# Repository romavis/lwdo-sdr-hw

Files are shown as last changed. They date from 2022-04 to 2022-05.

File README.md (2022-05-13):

# What

**LWDO-SDR** is an experimental device for wide-band LF/VLF radio reception and using LF/VLF signals for precise timekeeping and generic DSP/SDR research purposes.

The name LWDO-SDR *(**l**ong-**w**ave **d**isciplined **o**scillator with **s**oftware **d**efined **r**adio)* is a moniker aking to a widely-used *GPSDO* term, but instead of GPS we use signals transmitted within long wave radio band, and SDR for signal processing.

# Goals

LWDO-SDR is built upon following ideas:
- Wide dynamic range capture of the whole LF/VLF radio spectrum (up to 500 KHz)
  - Simultaneous reception of any number of stations
  - Exposing it as a WebSDR (for the fun of it?)
- Precise built-in VCTCXO oscillator
  - Generates tightly controlled ADC sample clock that allows for SDR processing using large-time-constant averaging
  - Digitally-controlled (via 16 bit DAC), and can be disciplined by:
    - External 1 PPS or 1,2,5,10MHz reference (via DPLL)
    - Received radio signals
- Synchronous capture from multiple antennas (up to 4)
  - Experiments with urban noise suppression SDR algorithms 
  - Directional reception (using e.g. two or three loop antennas)
- Raw data streaming over USB High Speed interface, processing on the USB host device (PC, RaspberryPi, etc.)
  - Because we don't want to be limited by computing power of an embedded MCU or DSP
- Single PCB, two form-factors:
  - Standalone, USB bus-powered - for ease of use and portability (uses Hammond 1455P1601 case)
  - Embedded, self-powered - for use within e.g. a standalone clock source unit within the home lab.

Some signals that can be received by LWDO-SDR are:
- [DCF77 - 77.5KHz](https://en.wikipedia.org/wiki/DCF77)
- [MSF - 60 KHz](https://en.wikipedia.org/wiki/Time_from_NPL_(MSF))
- [RBU - 66.67 KHz](https://en.wikipedia.org/wiki/RBU_(radio_station))
- [TDF - 162 KHz](https://en.wikipedia.org/wiki/ALS162_time_signal)
- [Loran - 100 KHz](https://en.wikipedia.org/wiki/Loran-C)

# Drawings

PDF renders:
- [Schematic](./doc/schematic-rev1.0.pdf)
- [PCB visualisation](./doc/pcb-rev1.0.pdf)

Curious ones are kindly asked to look into the original KiCad 6.0.4 CAD files, which include full PCB drawings and BOM information.

Photo of assembled board can be seen [here](./doc/pcb-photo-rev1.0.jpg).

# HW description

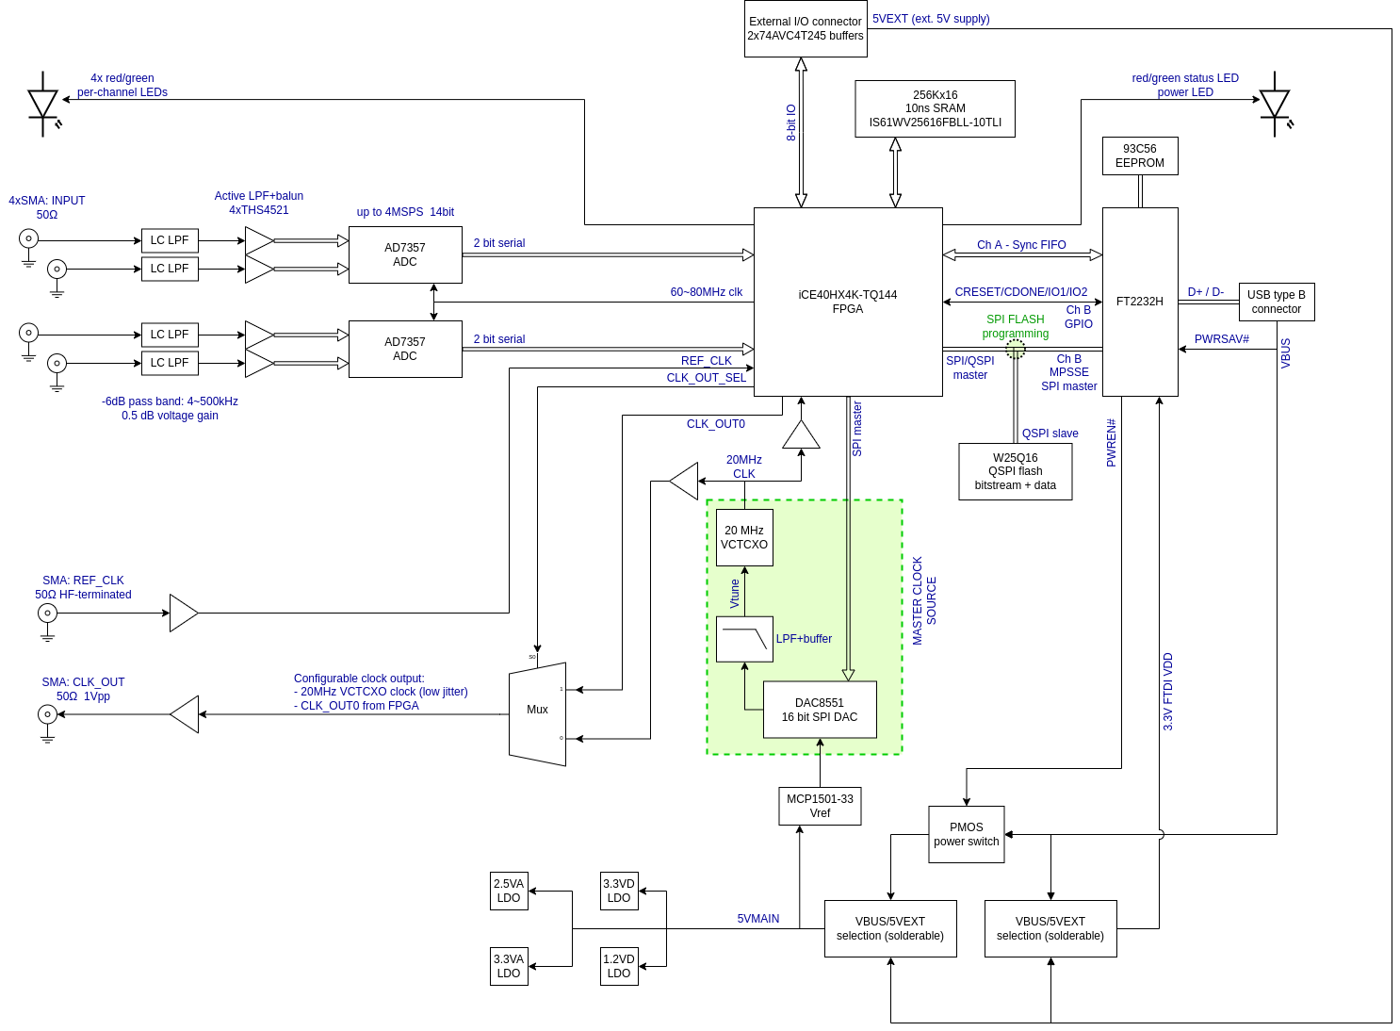
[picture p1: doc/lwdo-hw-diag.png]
Block diagram


### FPGA

The core of the LWDO-SDR is a low-end FPGA - *ICE40HX4K-TQ144* - that has:
- 3520x 4-input LUT, 1 FF logic cells (7680x with Yosys toolchain)
- 20x 4kbit dual-port block RAM cells (32x with Yosys)
- 2x PLLs
- DDR IO cells
- No hardware multipliers
- Typically achievable clock rates of 40~100MHz (depending on the design)

This FPGA has been chosen for its price and hobbyist-friendliness: TQFP144 can be soldered by hand and allows using 2-layer PCB. However, it is rather small so e.g. it may not be possible to use any kind of softCPU there (remains to be seen..). Any kind of sophisticated DSP is also out of the question, since there are no hardware multipliers.

The bitstream together with any extra user data is stored within 2 MByte QSPI flash - *W25Q16JV*.

FPGA is also connected to a 10 ns 512 KByte SRAM with 16 bit data bus - *IS61WV25616FBLL-10TLI*. At this moment it is not clear how much useful the SRAM may be, given overall FPGA footprint constraints.

### USB

USB 2.0 High Speed is implemented by FTDI FT2232H chip. It has two external channels, allocated as follows:
- Channel A - synchronous FIFO - allows data streaming from/to FPGA up to 40 MByte/s over USB bulk endpoints
- Channel B - MPSSE (SPI) + GPIO - to program bitstream SPI flash and handle CRESET, CDONE, and a pair of extra GPIO-like signals from FPGA (similar to how it's done on the [iCEstick](https://www.latticesemi.com/icestick). Available only when channel A is not in use.

### RF front-end

The board features four input channels for RF signals. All channels are the same:
1. 50 ohm DC-terminated SMA connector.
2. SD12C TVS ESD / overvoltage suppressor.
3. 2nd (3rd) order LC LPF (-3dB cutoff circa 530 KHz, rolloff 12 dB/oct).
4. Schottky diode overvoltage protection.
5. THS4521 fully-differential amplifier, performing unbalanced-balanced conversion and connected as a 2nd order LPF (-3dB cutoff circa 460 KHz, rolloff 12 dB/oct).
6. Passive RC LPF providing tank capacitance for driving the ADC (-3dB cutoff circa 1 MHz, rolloff 6 dB/oct)

### ADC

Board uses two [AD7357](https://www.analog.com/media/en/technical-documentation/data-sheets/AD7357.pdf), which is a 2-ch simulatenous-sampling 4.2 MSPS 14 bit SAR ADC. The output from each ADC is 2-bit serial bus. At a max sampling rate of 4.2 MSPS this ADC requires serial clock circa 80 MHz, which is provided by the FPGA.

**Note** to achieve timing closure for FPGA-ADC interface, taking into account propagation delays, setup times of ICE40HX IO cells, and especially AD7357 data valid delay (up to 9 ns), the generated clock is resampled on the FPGA pin:
- ICE40 outputs clock on the SCLK line (pin 15 or 20).
- ICE40 samples SCLK line via the input buffer of pin 20, and feeds that clock to the global clock net.
Compared to simply driving internal clock to the pin, this allows to take "global clock net -> pin output" delay (circa 2.5 ns) out of the timing equation.

### Clock source

[DOT050V-020.0M](http://www.conwin.com/datasheets/tx/tx395.pdf) VCTCXO from Connor-Winfield provides master 20 MHz clock for the FPGA, from which all the other clocks are generated using on-die PLLs.
DOT050V is a highly stable precision oscillator. Notable specs are:
- Factory frequency calibration: ±1 ppm
- Stability vs temperature 0~70 °C: ±50 **ppb**
- Stability vs load, supply voltage: ±20 ppb
- Aging over first year: ±300 ppb
- Voltage control frequency pulling range: at least ±10 ppm
- Comes in a standard 9x14mm SMT package

If needed, DOT050V can be easily replaced by some other, potentially cheaper, 3.3V VCTCXO or VCXO directly or through a simple adapter PCB (or DIY-style: some Kynar wire and hot glue). LWDO-SDR contains buffering circuitry that can accept oscillators with both square wave and (clipped) sine wave output.

The oscillator is voltage-controlled through by means of:
- 16-bit SPI DAC [DAC8551](https://www.ti.com/lit/ds/symlink/dac8551.pdf) driven by SPI master implemented on FPGA.
- DAC Vref provided by [MCP1501](https://ww1.microchip.com/downloads/en/DeviceDoc/20005474E.pdf), powered from filtered, unregulated 5V rail. 
- 1st order passive RC LPF (-3dB cutoff circa 160 Hz).
- Non-inverting buffer using [NCS325](www.onsemi.com/pub/Collateral/NCS325-D.PDF) rail-to-rail low-drift low-offset precision OpAmp.

### External clock input and output

There are two extra SMA connectors: one is for external clock input, one is for clock output from the board.

Clock output provides 1 Vpkpk 50 ohm terminated square wave output, AC or DC coupled (controlled by jumper). Output clock may come from one of two sources:
1. Dedicated FPGA pin.
2. 20 MHz master clock from VCTCXO.
The source is selected via a hardware LVCMOS multiplexer chip, controlled by the FPGA.

External clock input is 50 ohm terminated (above ~3MHz), AC or DC coupled. It is buffered and squared by a chain of unbuffered and buffered LVCMOS inverters, and fed to a dedicated FPGA pin.

**NOTE** clock input circuitry depicted on the schematic is sub-optimal. See "Errata" section below.

### External I/O

To allow LWDO-SDR PCB to be embedded, there's a 20-pin IDC ribbon cable connector which provides:
- 8 bit I/O bus connected to the FPGA:
  - Buffered via unidirectional 74AVC4T245 level translators.
  - Direction control for I/O lines is manual, by soldering/desoldering bridge resistors onto PCB.
  - Wired to a ribbon cable in G-S-G order, impedance-matched to a standard 1.27mm-pitch cable.
- External VDDIO supply for the level translators.
- External 5V supply for powering up the board (instead of using USB VBUS).

### LEDs

Board has 6 red/green bi-LEDs [WP130WCP/2EGW](https://www.kingbrightusa.com/images/catalog/SPEC/WP130WCP-2EGW.pdf):
- 4 for monitoring input status (located next to the input connectors)
- 1 for monitoring system status (located next to the USB)
- 1 hard-wired as a green power LED (located next to the USB)

### PCB

The board itself is 2-layer, designed to be manufacturable by [Eurocircuits](https://www.eurocircuits.com/) PCB Proto service according to Class 5C (0.175mm track, 0.25mm annular ring, 0.25mm smallest final hole).

# Software

The testing of rev 1.0 board is, as of 10 May 2022, currently ongoing. The software development is WIP. Source code of FPGA and host SW will be published on GitHub as soon as I have something ready.

# Errata

### Issue 1 - CLK_IN buffer instability

**Symptom:** when AC-coupled, in absence of input signal, or when input signal is weak or slowly-changing (low frequency sine wave), the output of clock buffer contains a lot of random 0->1, 1->0 transitions.

**Cause:** input buffer, implemented with 2x LVCMOS unbuffered invertors, has very high analog gain (circa 40~50dB). That amplifies all kinds of noise when the input signal is not strong enough. Buffered LVCMOS invertors ampify and square that noise signal even further.

**Solution:** problem can be solved by adding hysteresis (Schmitt-trigger action) to the input buffer. For that, an extra 100K resistor needs to be soldered on top of the PCB per schematic shown below:

[Errata-1-rework-schematic](./doc/errata-issue1-rework.png)

# License

Copyright 2022 Roman Dobrodii

SPDX-License-Identifier: Apache-2.0 WITH SHL-2.1

Licensed under the Solderpad Hardware License v 2.1 (the “License”); you may not
use this work except in compliance with the License, or, at your option, the
Apache License version 2.0. You may obtain a copy of the License at

https://solderpad.org/licenses/SHL-2.1/

Unless required by applicable law or agreed to in writing, any work distributed
under the License is distributed on an “AS IS” BASIS, WITHOUT WARRANTIES OR
CONDITIONS OF ANY KIND, either express or implied. See the License for the
specific language governing permissions and limitations under the License.

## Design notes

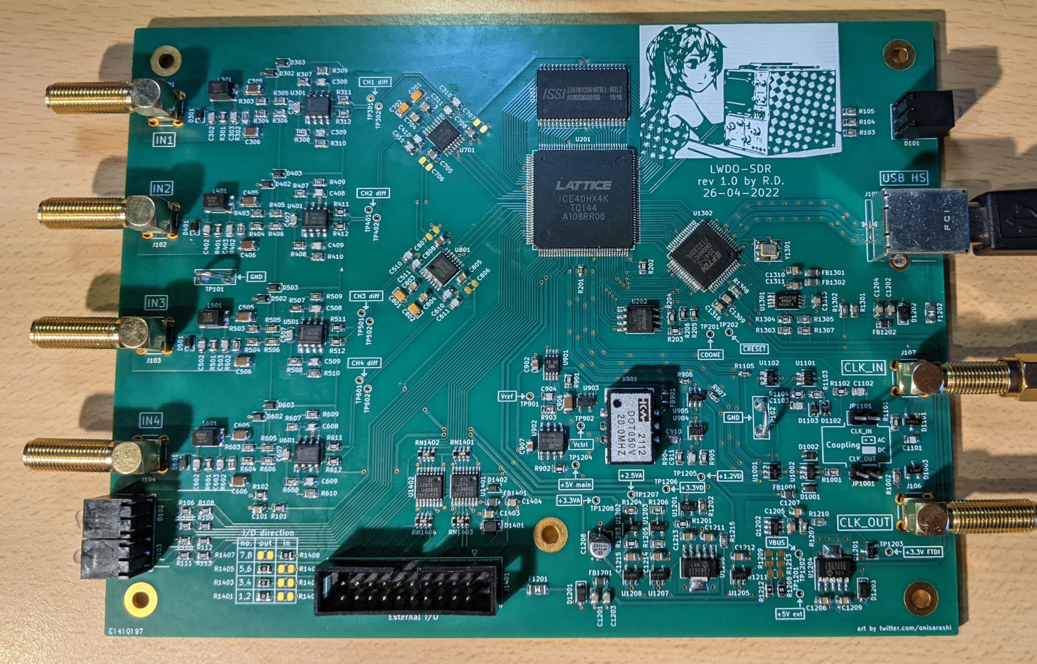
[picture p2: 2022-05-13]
doc/pcb-photo-rev1.0.jpg

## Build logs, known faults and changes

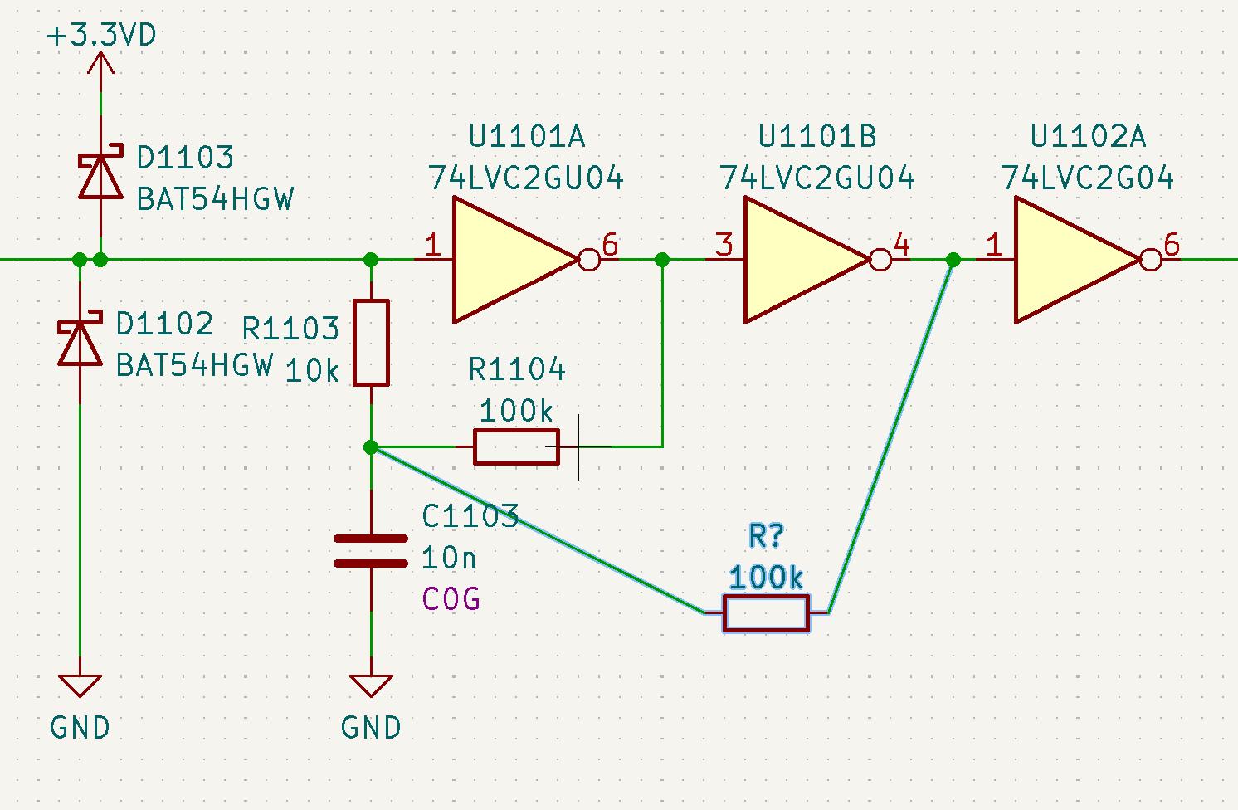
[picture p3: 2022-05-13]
doc/errata-issue1-rework.png

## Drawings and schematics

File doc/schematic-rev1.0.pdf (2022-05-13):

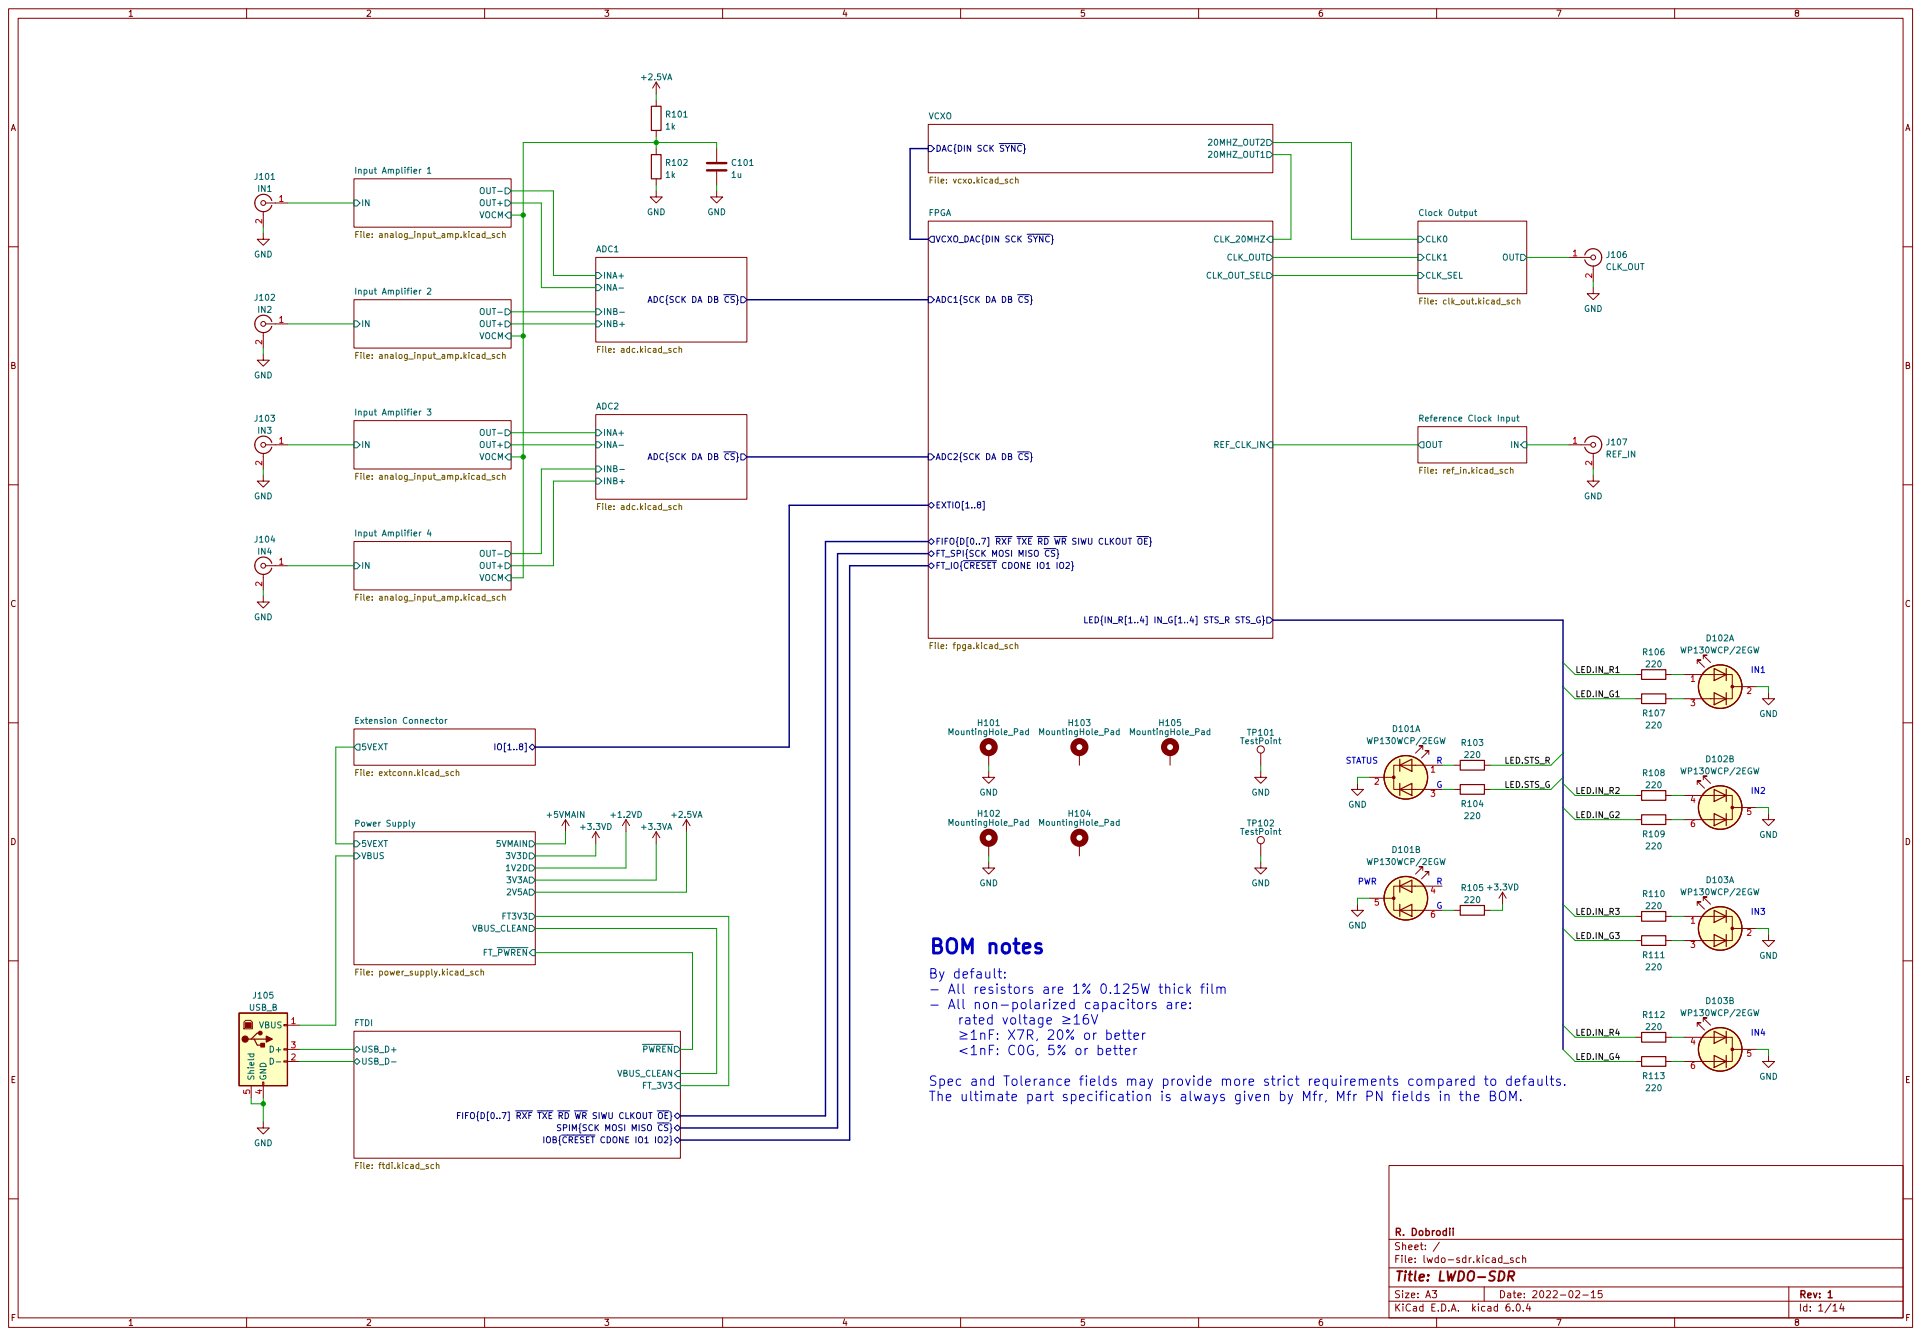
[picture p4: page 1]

20MHZ_OUT2 DAC{DIN SCK ~{SYNC}} VCXO

ADC{SCK DA DB ~{CS}}

ADC1{SCK DA DB ~{CS}}

Reference Clock Input File: ref_in.kicad_sch

ADC2{SCK DA DB ~{CS}}

FIFO{D[0..7] ~{RXF} ~{TXE} ~{RD} ~{WR} SIWU CLKOUT ~{OE}}

- All resistors are 1% 0.125W thick film
- All non-polarized capacitors are:
<1nF: C0G, 5% or better

IOB{~{CRESET} CDONE IO1 IO2} USB_D- USB_D+ FTDI File: ftdi.kicad_sch

FIFO{D[0..7] ~{RXF} ~{TXE} ~{RD} ~{WR} SIWU CLKOUT ~{OE}} VBUS_CLEAN

Spec and Tolerance fields may provide more strict requirements compared to defaults.

SPIM{SCK MOSI MISO ~{CS}}

File: lwdo-sdr.kicad_sch Sheet: / R. Dobrodii

Id: 1/14 Title: LWDO-SDR

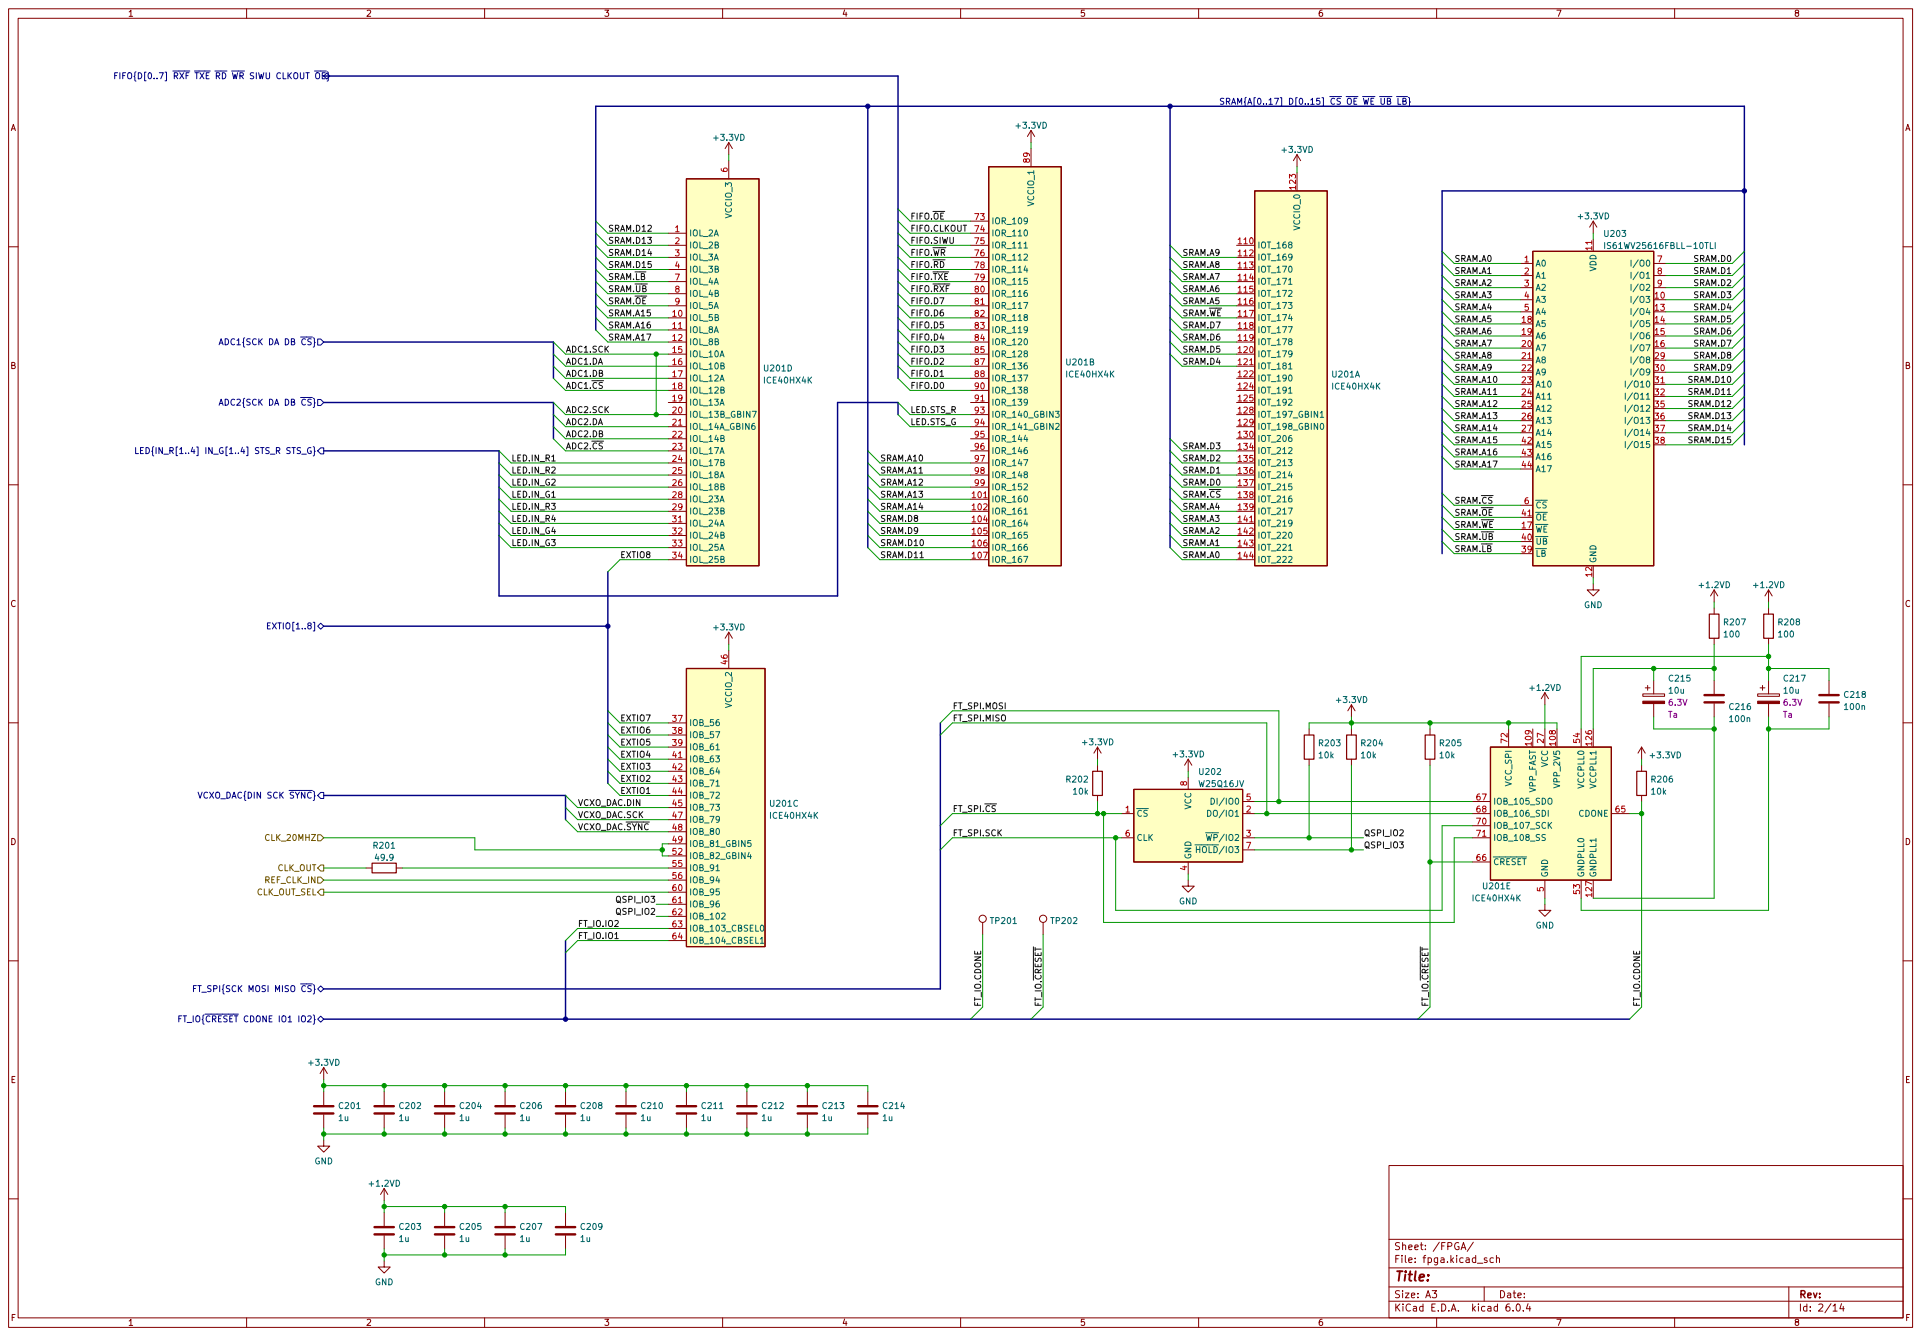
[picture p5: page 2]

FIFO{D[0..7] ~{RXF} ~{TXE} ~{RD} ~{WR} SIWU CLKOUT ~{OE}}

ADC1{SCK DA DB ~{CS}}

SRAM.A13 SRAM.A11 FIFO.D0 SRAM.A12

SRAM.~{UB} SRAM.A13 SRAM.A12

VCXO_DAC{DIN SCK ~{SYNC}} CLK_OUT EXTIO[1..8]

4 DI/IO0 5 CLK 6 ~{HOLD}/IO3 7 VCC

FT_SPI{SCK MOSI MISO ~{CS}}

File: fpga.kicad_sch Sheet: /FPGA/

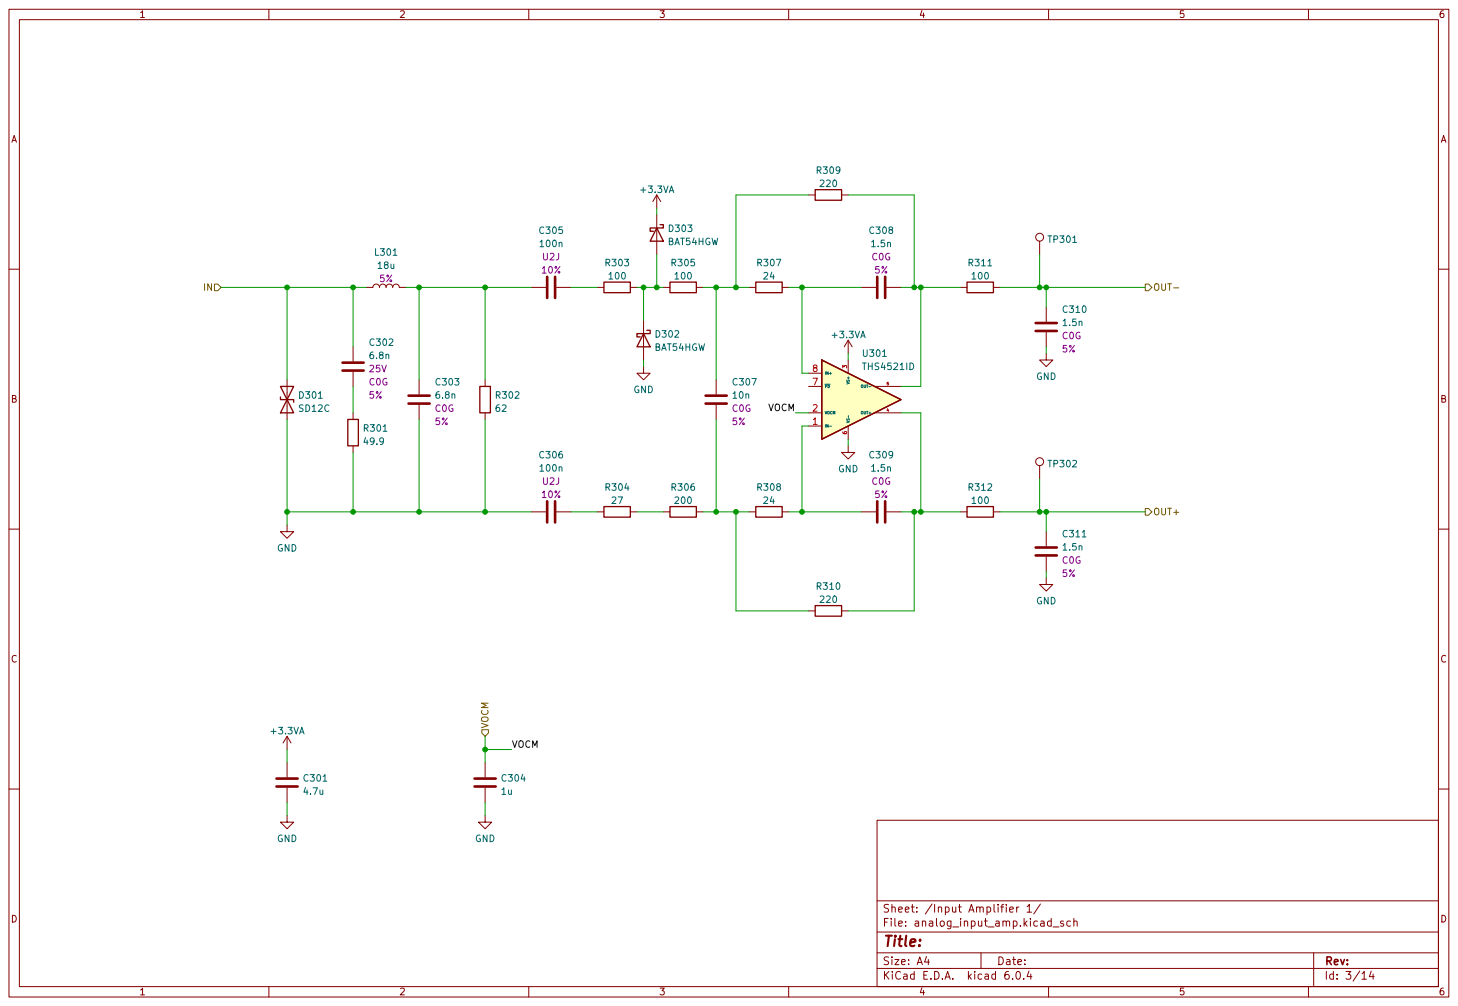
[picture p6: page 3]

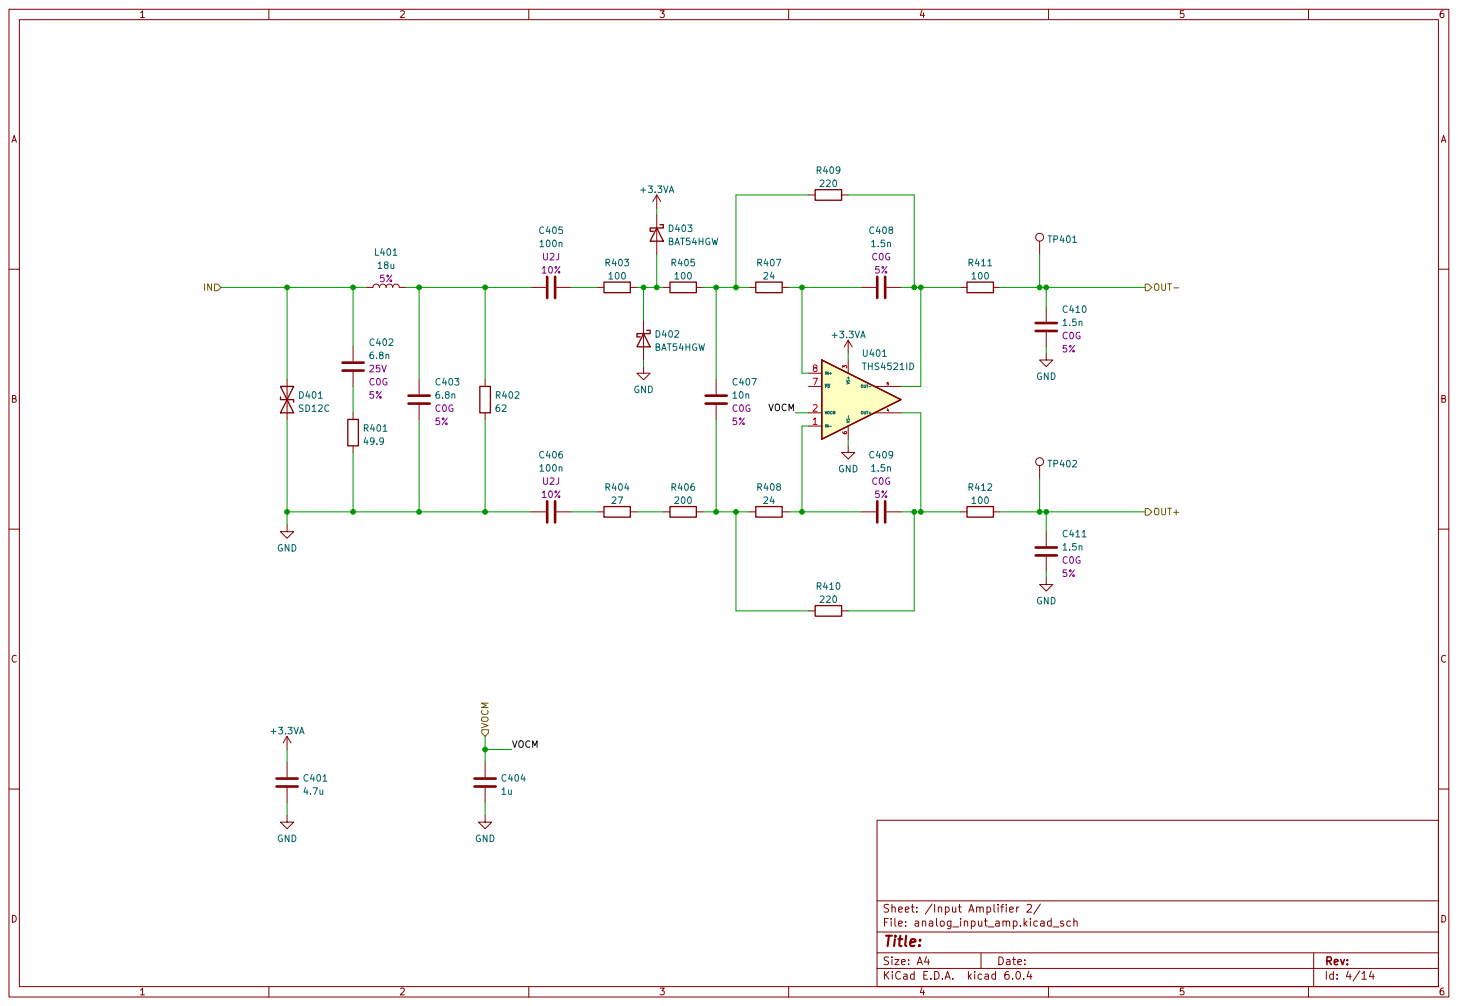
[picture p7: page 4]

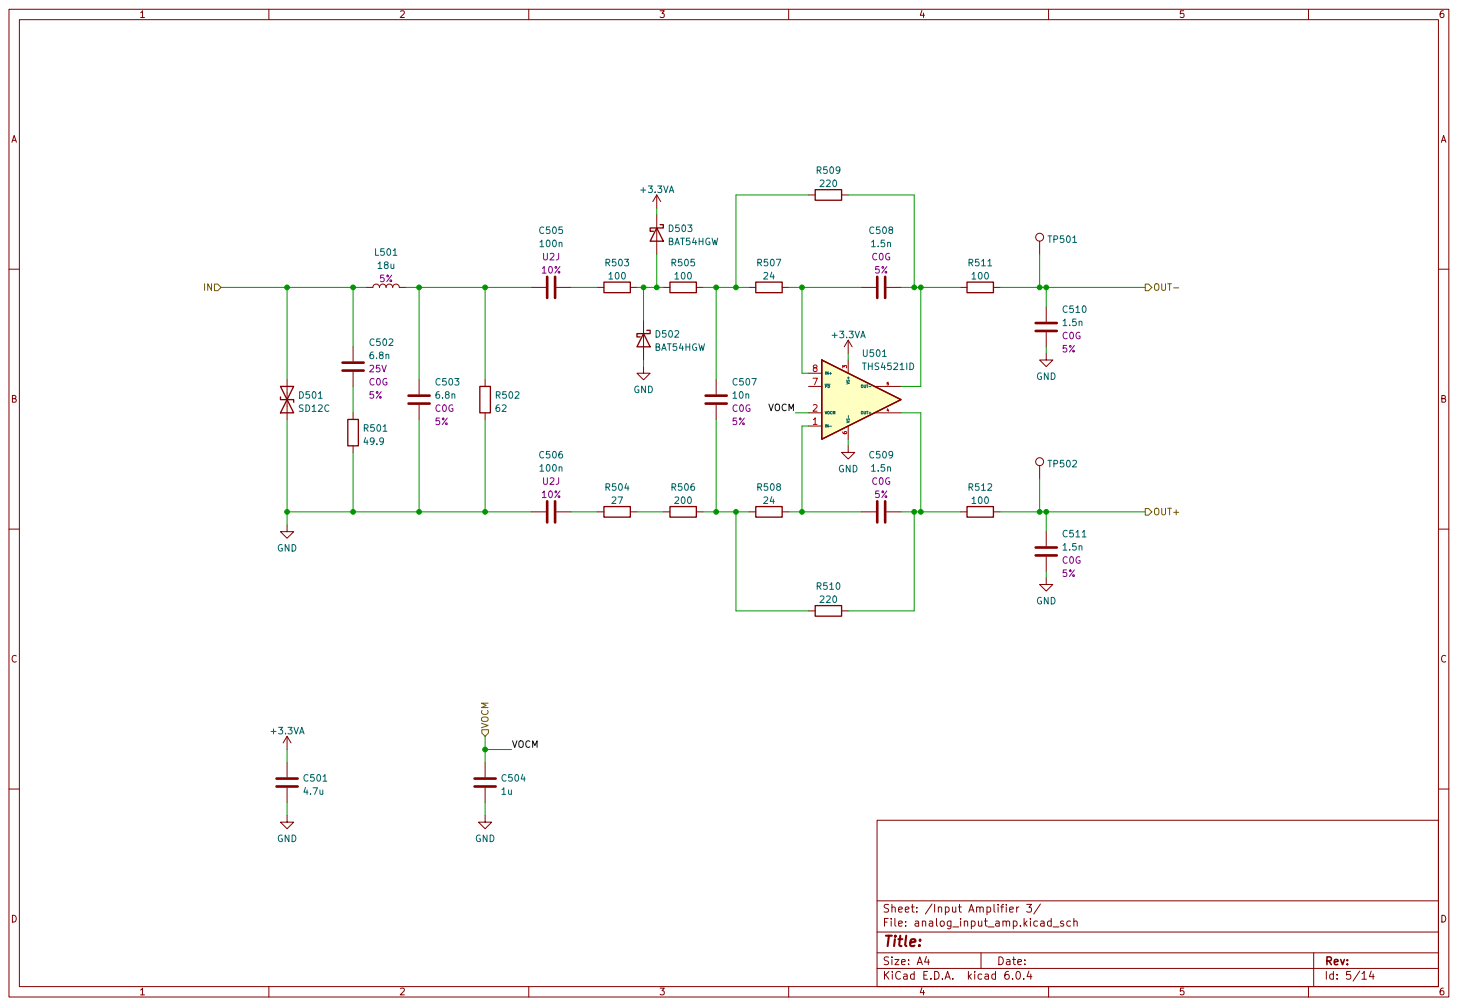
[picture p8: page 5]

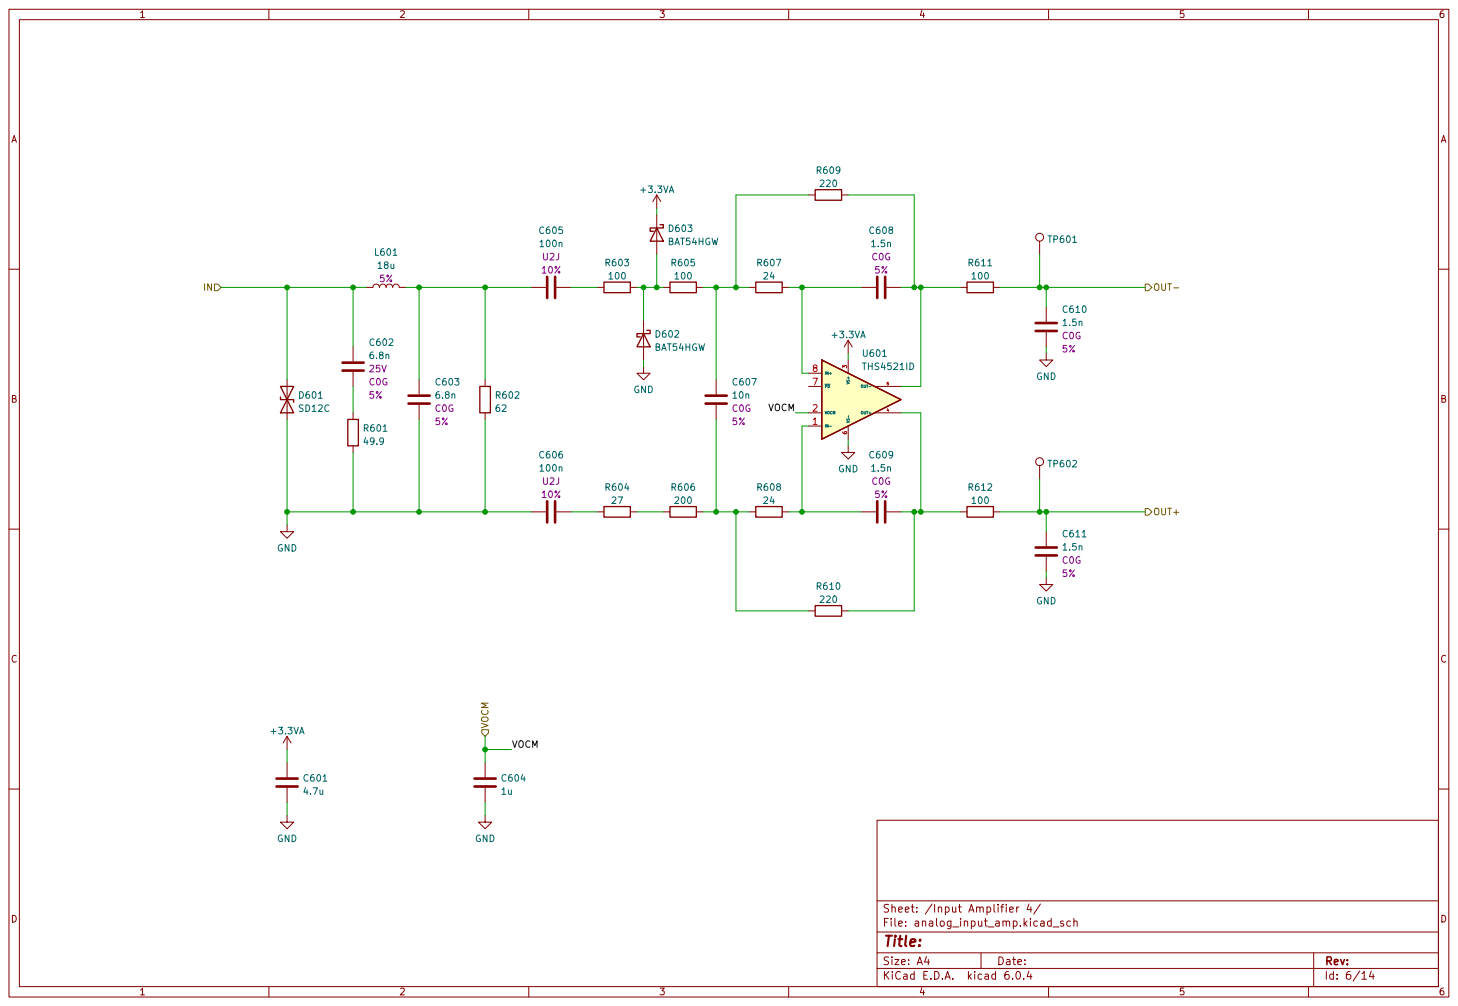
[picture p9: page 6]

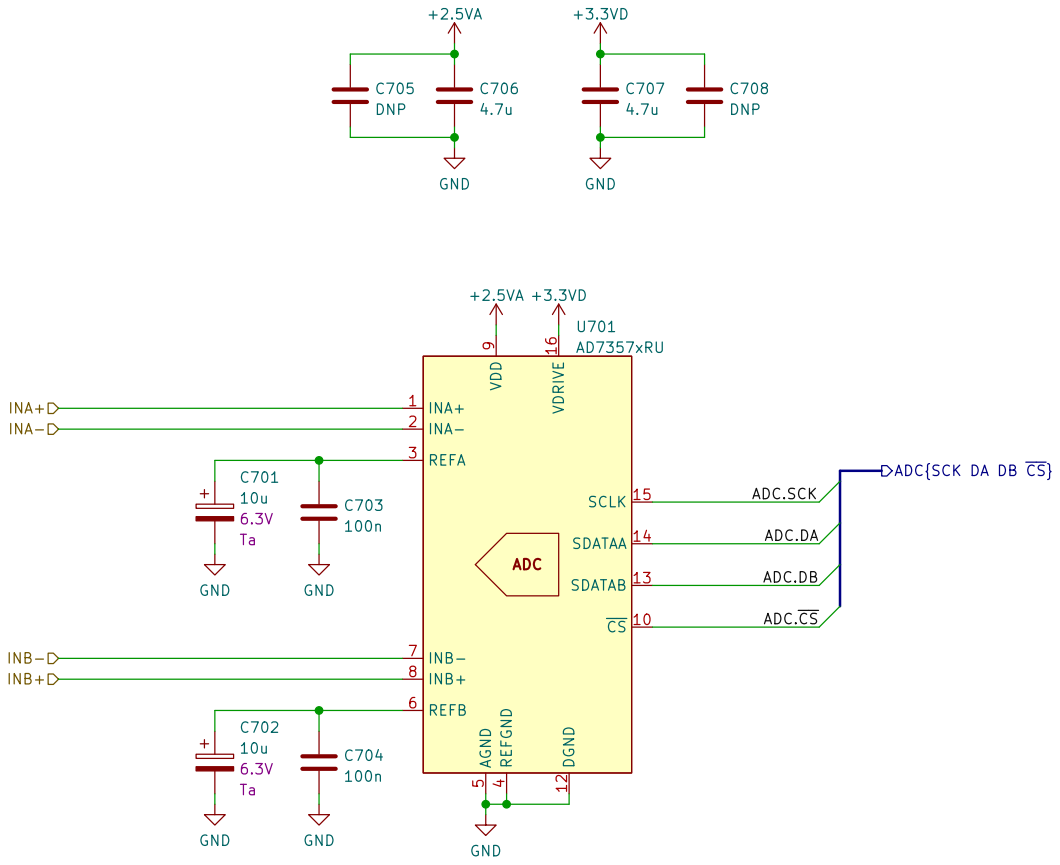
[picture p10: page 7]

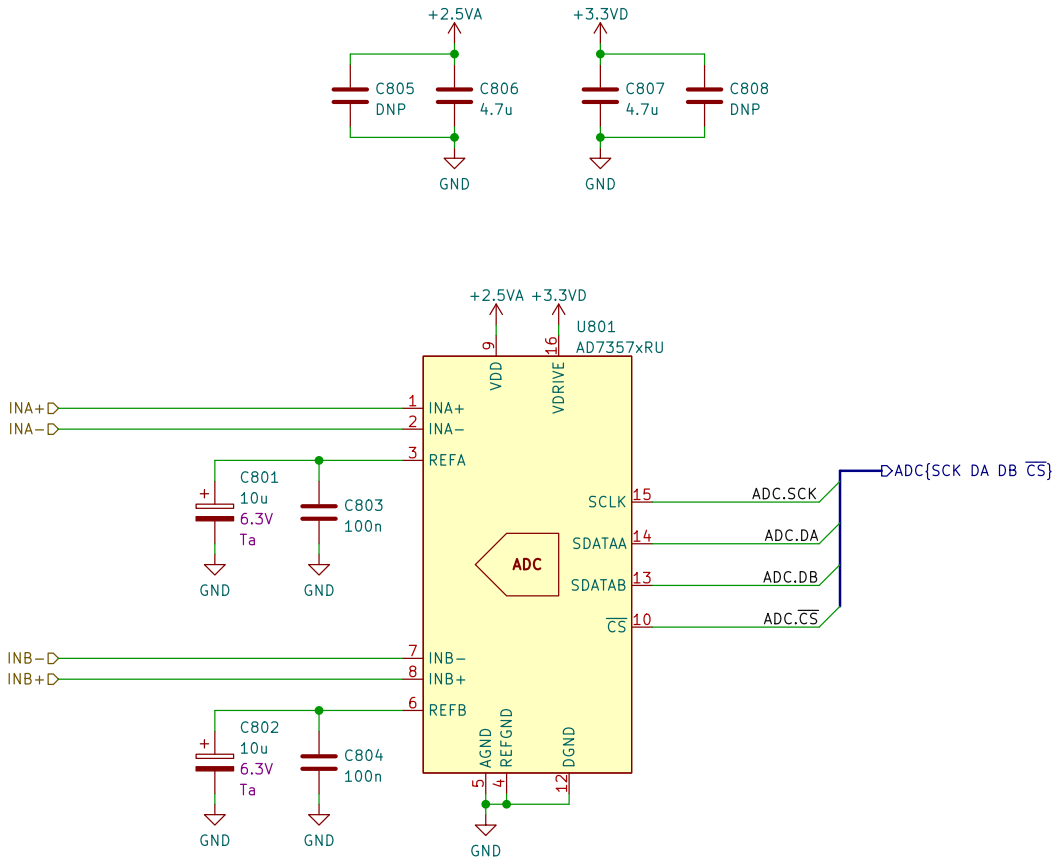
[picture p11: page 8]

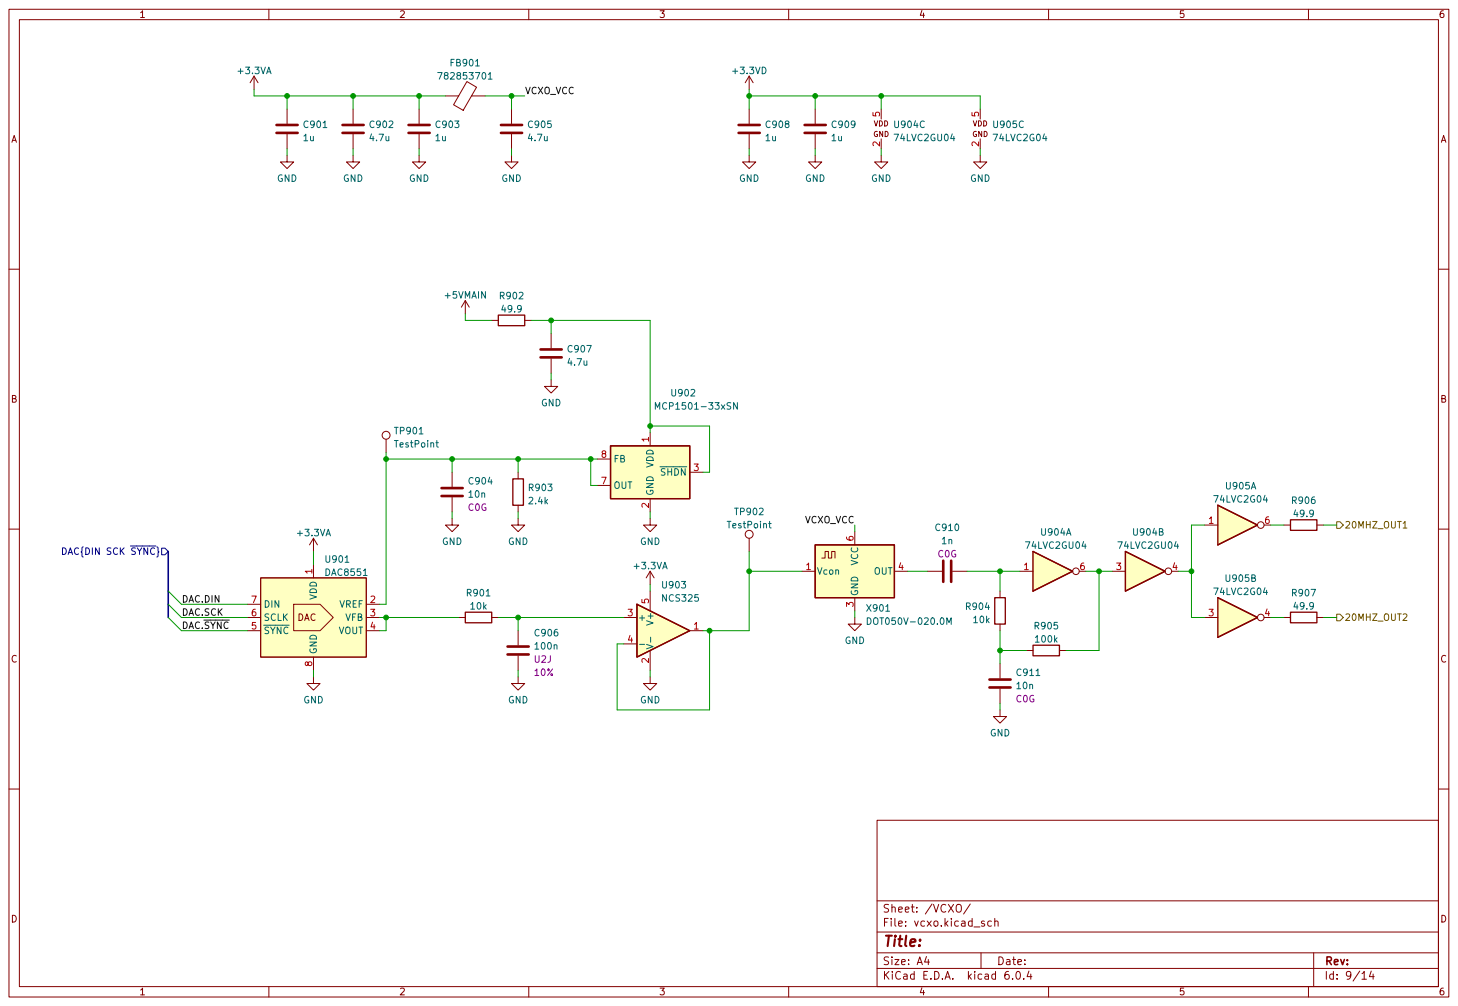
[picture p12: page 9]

2 ~{SHDN} 3 OUT 7 FB 8 U902 GND MCP1501-33xSN

1 VREF 2 VFB 3 VOUT 4 ~{SYNC} 5 SCLK 6 DIN 7 GND

DAC.DIN
DAC.~{SYNC} DAC.SCK

File: vcxo.kicad_sch Sheet: /VCXO/
Id: 9/14 Title:

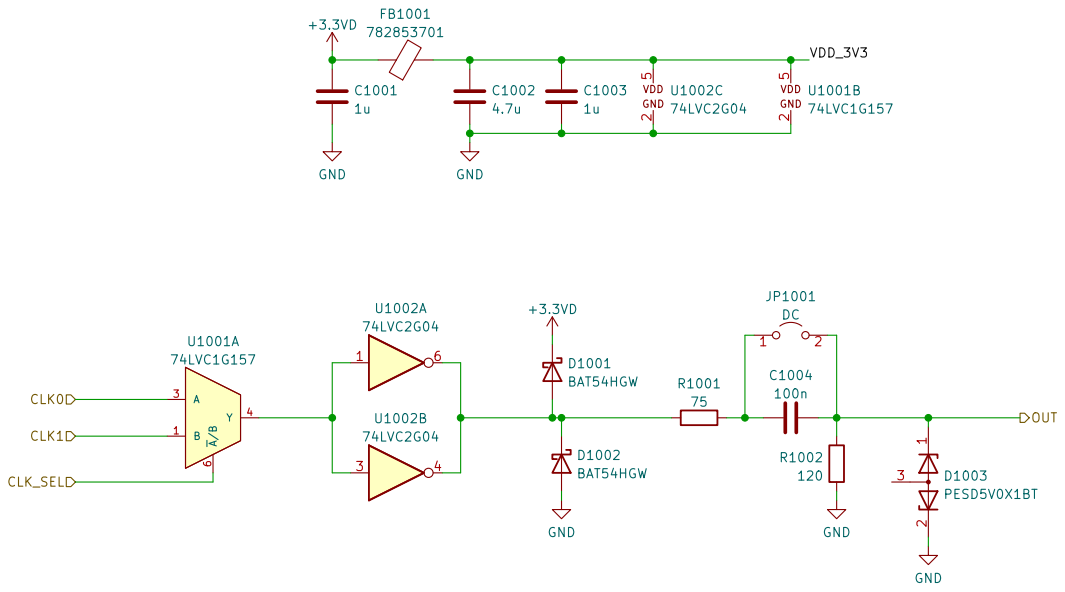
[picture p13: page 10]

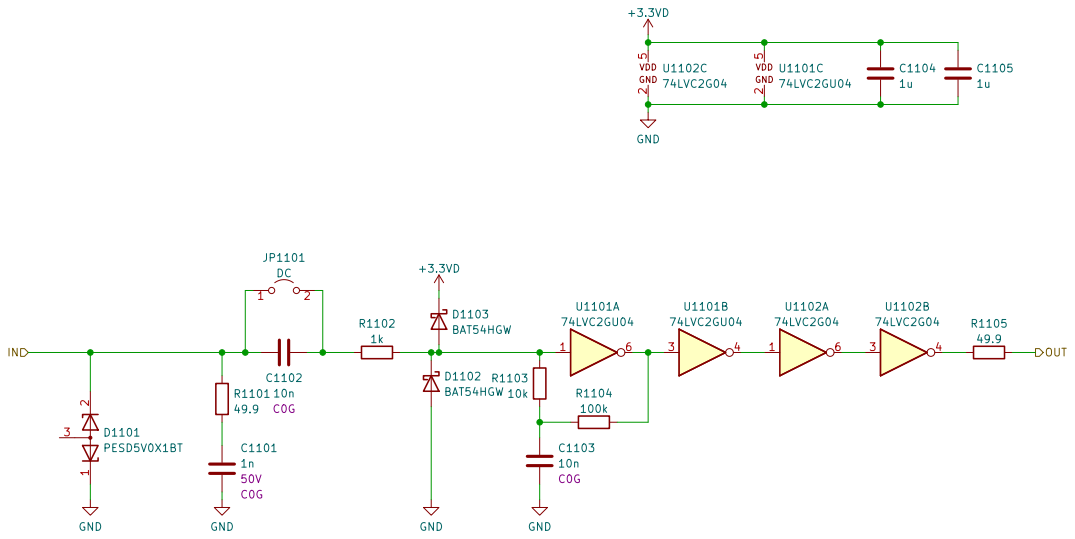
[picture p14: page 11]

Sheet: /Reference Clock Input/ D1103 BAT54HGW

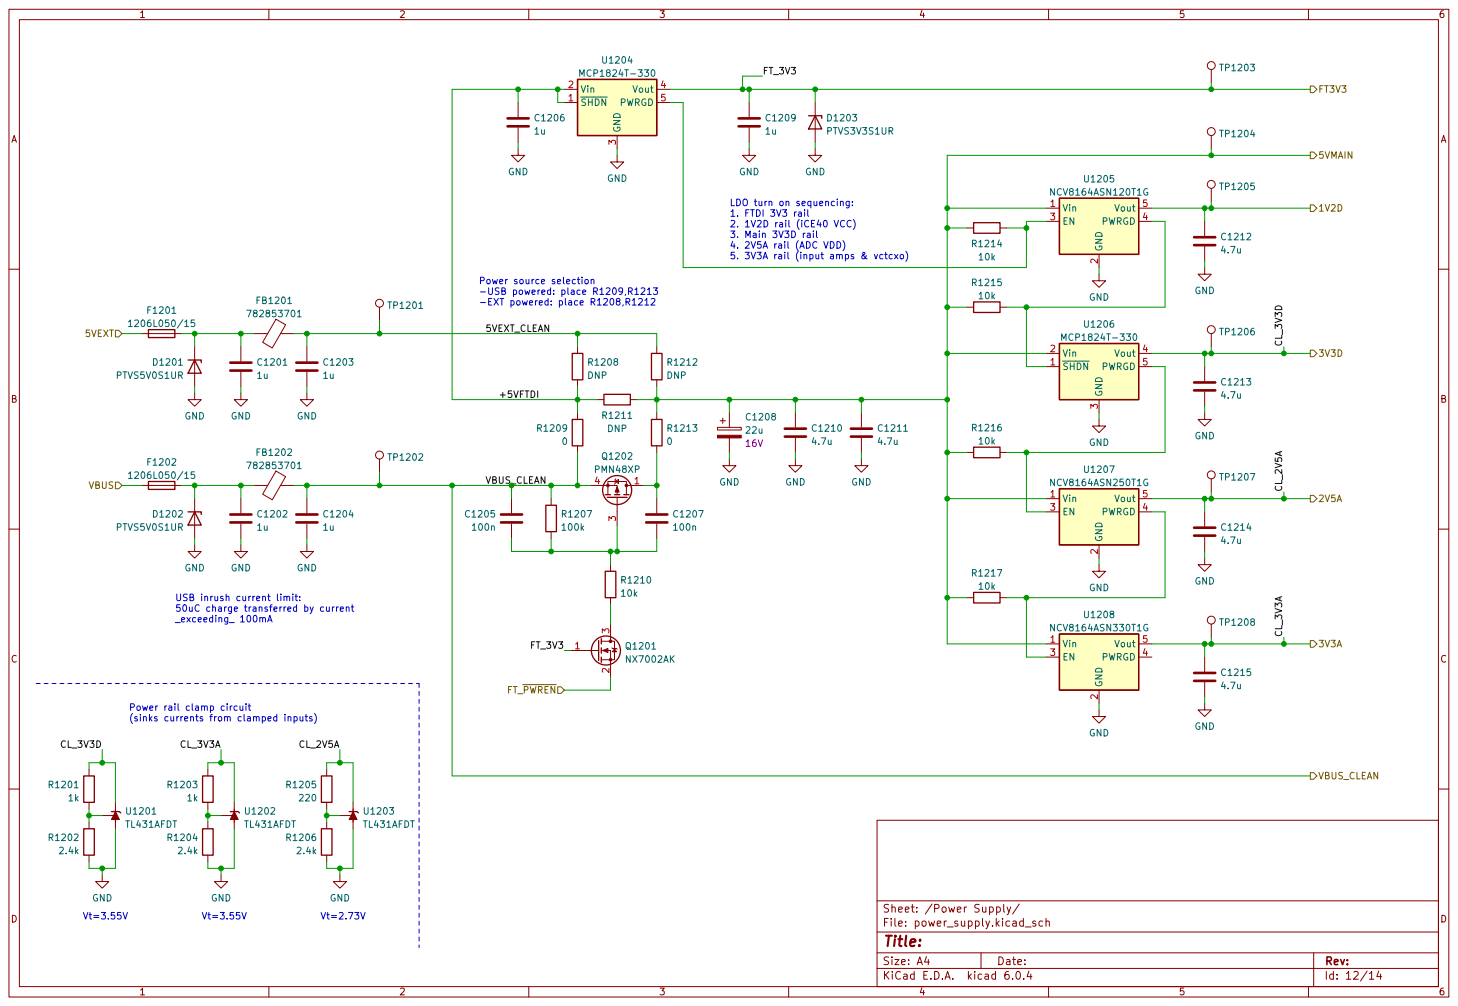
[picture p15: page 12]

LDO turn on sequencing: 1. FTDI 3V3 rail 2. 1V2D rail (iCE40 VCC) 3. Main 3V3D rail 4. 2V5A rail (ADC VDD)

5. 3V3A rail (input amps & vctcxo)

Power rail clamp circuit


1 AGND 10 GND 11 VCORE 12 TEST 13 ~{RESET} 14 GND 15 ADBUS0 16 ADBUS1 17 ADBUS2 18 ADBUS3 19 OSCI 2 VCCIO 20 ADBUS4 21 ADBUS5 22 ADBUS6 23 ADBUS7 24 GND 25 ACBUS0 26 ACBUS1 27 ACBUS2 28 ACBUS3 29 OSCO 3 ACBUS4 30 VCCIO 31 ACBUS5 32 ACBUS6 33 ACBUS7 34 GND 35

4 BDBUS2 40 BDBUS3 41 VCCIO 42 BDBUS4 43 BDBUS5 44 BDBUS6 45 BDBUS7 46 GND 47 BCBUS0 48 VREGOUT 49 GND

5 VREGIN 50 GND 51 BCBUS1 52 BCBUS2 53 BCBUS3 54 BCBUS4 55 VCCIO 56 BCBUS5 57 BCBUS6 58 BCBUS7 59 REF 6 ~{PWREN} 60 EEDATA 61 EECLK 62 EECS 63 VCORE 64 DM 7 DP 8 VPLL

File: ftdi.kicad_sch Sheet: /FTDI/ R1302


Level shifter direction control: L: B->A (pin is input)
DIR78 VDDIO
R1404 DNP VCCA

15 | 16
17 | 18
19 | 20

File: extconn.kicad_sch Sheet: /Extension Connector/
Id: 14/14 Title:


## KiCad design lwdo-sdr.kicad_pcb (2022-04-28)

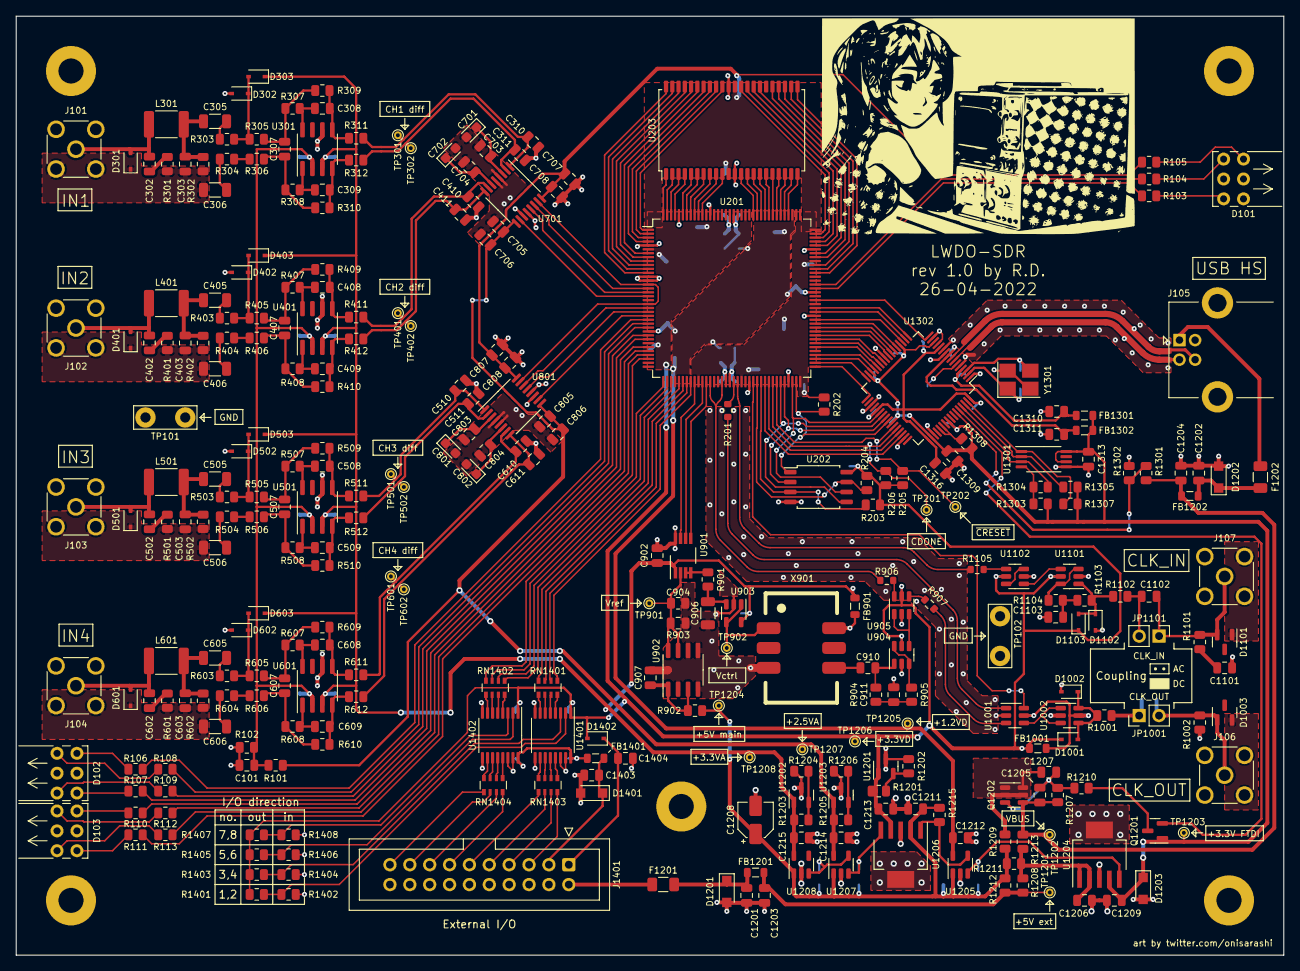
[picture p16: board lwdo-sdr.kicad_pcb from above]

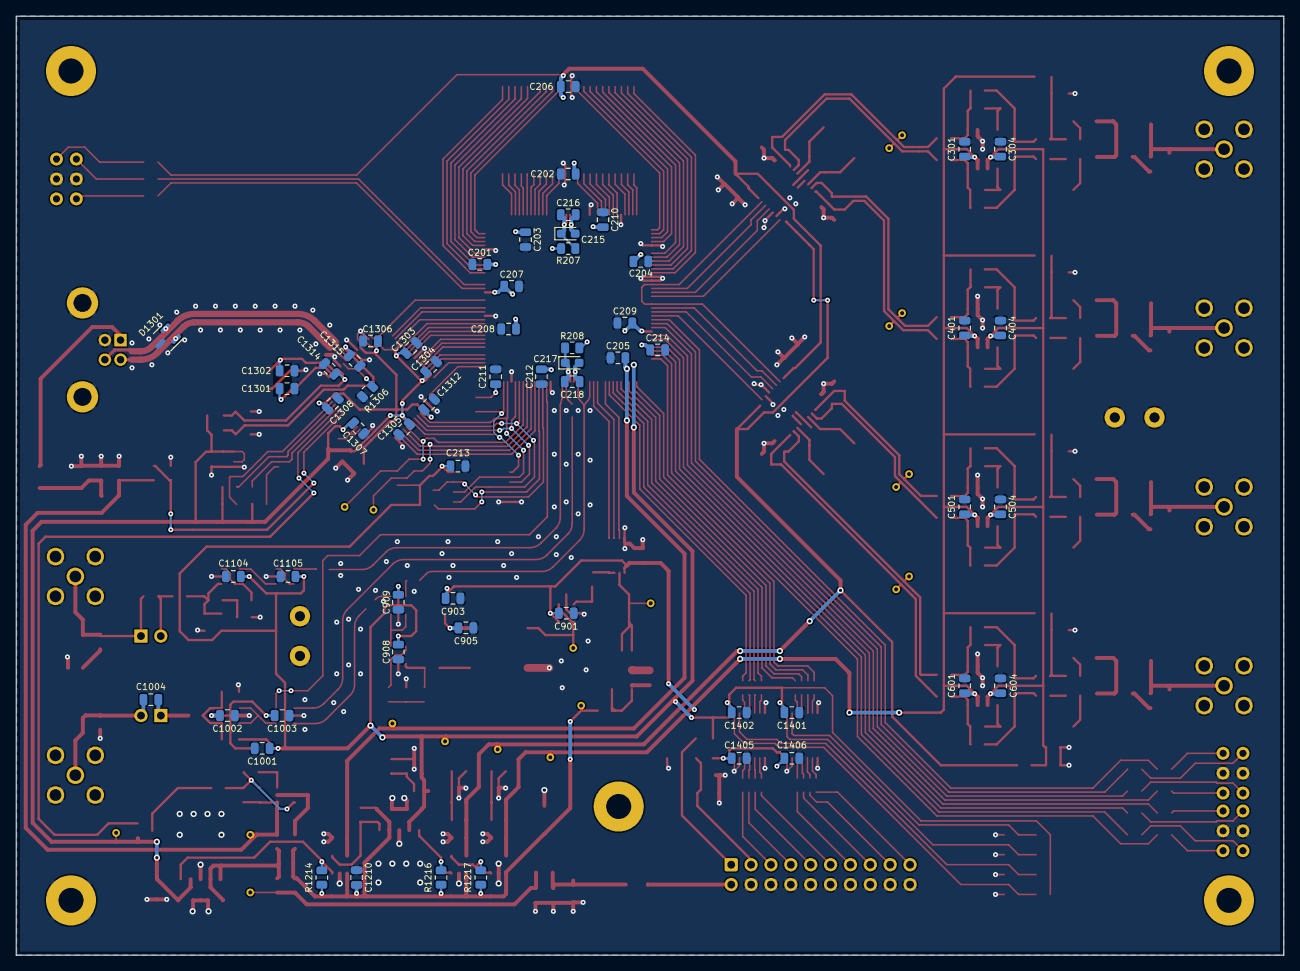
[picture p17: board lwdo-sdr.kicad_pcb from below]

Board: 2 copper layers, 162.0 x 120.0 mm, 367 parts (60 on the bottom side), 275 nets.

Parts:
C101, C201, C202, C203, C204, C205, C206, C207, C208, C209, C210, C211, C212, C213, C214, C304, C404, C504, C604, C901, C903, C908, C909, C1001, C1003, C1104, C1105, C1201, C1202, C1203, C1204, C1206, C1209, C1303, C1304, C1305, C1306, C1307, C1308, C1309, C1310, C1311, C1312, C1313, C1314, C1315, C1316, C1401, C1402, C1403, C1404, C1406: 1u; C_0805_2012Metric
C215, C217, C701, C702, C801, C802: 10u; CP_EIA-2012-15_AVX-P
C216, C218, C703, C704, C803, C804, C1004, C1205, C1207: 100n; C_0805_2012Metric
C301, C401, C501, C601, C706, C707, C806, C807, C902, C905, C907, C1002, C1210, C1211, C1212, C1213, C1214, C1215, C1405: 4.7u; C_0805_2012Metric
C302, C303, C402, C403, C502, C503, C602, C603: 6.8n; C_0805_2012Metric
C305, C306, C405, C406, C505, C506, C605, C606, C906: 100n; C_1206_3216Metric
C307, C407, C507, C607, C904, C911, C1102, C1103: 10n; C_0805_2012Metric
C308, C309, C310, C311, C408, C409, C410, C411, C508, C509, C510, C511, C608, C609, C610, C611: 1.5n; C_0805_2012Metric
C705, C708, C805, C808: DNP; C_0805_2012Metric
C910, C1101: 1n; C_0805_2012Metric
C1208: 22u; CP_Elec_4x5.8
C1301, C1302: 27p; C_0805_2012Metric
D101, D102, D103: WP130WCP/2EGW; WP130WCP
D301, D401, D501, D601: SD12C; D_SOD-323
D302, D303, D402, D403, D502, D503, D602, D603, D1001, D1002, D1102, D1103, D1402: BAT54HGW; D_SOD-323
D1003, D1101: PESD5V0X1BT; SOT-23
D1201, D1202: PTVS5V0S1UR; Nexperia_CFP3_SOD-123W
D1203, D1401: PTVS3V3S1UR; Nexperia_CFP3_SOD-123W
D1301: PESD2USB3UV; SOT-23
F1201, F1202: 1206L050/15; Fuse_1206_3216Metric
FB901, FB1001, FB1201, FB1202, FB1301, FB1302, FB1401: 782853701; L_0805_2012Metric
H101, H102, H103, H104, H105: MountingHole_Pad; MountingHole_3.2mm_M3_Pad
J101: IN1; SMA_Molex_73251-2200_Horizontal
J102: IN2; SMA_Molex_73251-2200_Horizontal
J103: IN3; SMA_Molex_73251-2200_Horizontal
J104: IN4; SMA_Molex_73251-2200_Horizontal
J105: USB_B; USB_B_Lumberg_2411_02_Horizontal
J106: CLK_OUT; SMA_Molex_73251-2200_Horizontal
J107: REF_IN; SMA_Molex_73251-2200_Horizontal
J1401: Conn_02x10_Odd_Even; IDC-Header_2x10_P2.54mm_Vertical
JP1001, JP1101: DC; PinHeader_1x02_P2.54mm_Vertical
L301, L401, L501, L601: 18u; L_1812_4532Metric_Pad1.30x3.40mm_HandSolder
Q1201: NX7002AK; SOT-23
Q1202: PMN48XP; SOT-23-6
R101, R102, R1102, R1201, R1203: 1k; R_0805_2012Metric
R103, R104, R105, R106, R107, R108, R109, R110, R111, R112, R113, R309, R310, R409, R410, R509, R510, R609, R610, R1205: 220; R_0805_2012Metric
R201, R906, R907, R1105: 49.9; R_0603_1608Metric
R202, R203, R204, R205, R206, R901, R904, R1103, R1210, R1214, R1215, R1216, R1217, R1302, R1303, R1305, R1307, R1308: 10k; R_0805_2012Metric
R207, R208, R303, R305, R311, R312, R403, R405, R411, R412, R503, R505, R511, R512, R603, R605, R611, R612: 100; R_0805_2012Metric
R301, R401, R501, R601, R902, R1101: 49.9; R_0805_2012Metric
R302, R402, R502, R602: 62; R_0805_2012Metric
R304, R404, R504, R604: 27; R_0805_2012Metric
R306, R406, R506, R606: 200; R_0805_2012Metric
R307, R308, R407, R408, R507, R508, R607, R608: 24; R_0805_2012Metric
R903, R1202, R1204, R1206, R1304: 2.4k; R_0805_2012Metric
R905, R1104, R1207: 100k; R_0805_2012Metric
R1001: 75; R_0805_2012Metric
R1002: 120; R_0805_2012Metric
R1208, R1211, R1212, R1402, R1404, R1406, R1407: DNP; R_0805_2012Metric
R1209, R1213, R1401, R1403, R1405, R1408: 0; R_0805_2012Metric
R1301: 5.1k; R_0805_2012Metric
R1306: 12k; R_0805_2012Metric
RN1401, RN1402, RN1403, RN1404: 4x82R; R_Array_Convex_4x0603
TP101, TP102: TestPoint; TestPoint_Bridge_Pitch5.08mm_Drill1.3mm
TP201, TP202, TP301, TP302, TP401, TP402, TP501, TP502, TP601, TP602, TP901, TP902, TP1201, TP1202, TP1203, TP1204, TP1205, TP1206, TP1207, TP1208: TestPoint; TestPoint_THTPad_D1.0mm_Drill0.5mm
U201: ICE40HX4K; TQFP-144_20x20mm_P0.5mm
U202: W25Q16JV; SOIC-8_5.23x5.23mm_P1.27mm
U203: IS61WV25616FBLL-10TLI; TSOP-II-44_10.16x18.41mm_P0.8mm
U301, U401, U501, U601: THS4521ID; SOIC-8_3.9x4.9mm_P1.27mm
U701, U801: AD7357xRU; TSSOP-16_4.4x5mm_P0.65mm
U901: DAC8551; VSSOP-8_3.0x3.0mm_P0.65mm
U902: MCP1501-33xSN; SOIC-8_3.9x4.9mm_P1.27mm
U903: NCS325; SOT-23-5
U904, U1101: 74LVC2GU04; SOT-23-6
U905, U1002, U1102: 74LVC2G04; SOT-23-6
U1001: 74LVC1G157; SOT-23-6
U1201, U1202, U1203: TL431AFDT; SOT-23
U1204, U1206: MCP1824T-330; SOT-223-6
U1205: NCV8164ASN120T1G; SOT-23-5
U1207: NCV8164ASN250T1G; SOT-23-5
U1208: NCV8164ASN330T1G; SOT-23-5
U1301: AT93C56; TSSOP-8_4.4x3mm_P0.65mm
U1302: FT2232HL; LQFP-64_10x10mm_P0.5mm
U1401, U1402: 74AVC4T245PW; TSSOP-16_4.4x5mm_P0.65mm
X901: DOT050V-020.0M; ConnorWinfield_DOT050
Y1301: 12MHz CL=18p; Crystal_SMD_3225-4Pin_3.2x2.5mm_HandSoldering

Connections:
+1.2VD: C203.1, C205.1, C207.1, C209.1, C1212.1, R207.2, R208.2, TP1205.1, U201.27 (VCC), U201.40 (VCC), U201.92 (VCC), U201.111 (VCC), U1205.5 (Vout)
+2.5VA: C705.1, C706.1, C805.1, C806.1, C1214.1, R101.2, R1205.1, TP1207.1, U701.9 (VDD), U801.9 (VDD), U1203.1 (K), U1207.5 (Vout)
+3.3VA: C301.1, C401.1, C501.1, C601.1, C901.2, C902.2, C903.2, C1215.1, D303.1 (K), D403.1 (K), D503.1 (K), D603.1 (K), FB901.1, R1203.1, TP1208.1, U301.3 (VS+), U401.3 (VS+), U501.3 (VS+), U601.3 (VS+), U901.1 (VDD), U903.5 (V+), U1202.1 (K), U1208.5 (Vout)
+3.3VD: C201.1, C202.1, C204.1, C206.1, C208.1, C210.1, C211.1, C212.1, C213.1, C214.1, C707.1, C708.1, C807.1, C808.1, C908.2, C909.2, C1001.2, C1104.2, C1105.2, C1213.1, C1401.1, C1402.1, D1001.1 (K), D1103.1 (K), D1402.2 (A), FB1001.1, R105.1, R202.1, R203.1, R204.1, R205.1, R206.1, R1201.1, R1401.2, R1403.2, R1405.2, R1407.2, TP1206.1, U201.6 (VCCIO_3), U201.30 (VCCIO_3), U201.46 (VCCIO_2), U201.57 (VCCIO_2), U201.72 (VCC_SPI), U201.89 (VCCIO_1), U201.100 (VCCIO_1), U201.108 (VPP_2V5), U201.123 (VCCIO_0), U201.131 (VCCIO_0), U202.8 (VCC), U203.11 (VDD), U203.33 (VDD), U701.16 (VDRIVE), U801.16 (VDRIVE), U904.5, U905.5, U1101.5, U1102.5, U1201.1 (K), U1206.4 (Vout), U1401.1 (VCCA), U1402.1 (VCCA)
+5VMAIN: C1208.1, C1210.1, C1211.1, R902.2, R1211.2, R1212.1, R1213.2, R1214.2, R1215.2, R1216.2, R1217.2, TP1204.1, U1205.1 (Vin), U1206.2 (Vin), U1207.1 (Vin), U1208.1 (Vin)
/ADC1/ADC.DA: U201.16 (IOL_10B), U701.14 (SDATAA)
/ADC1/ADC.DB: U201.17 (IOL_12A), U701.13 (SDATAB)
/ADC1/ADC.~CS: U201.18 (IOL_12B), U701.10 (~CS)
/ADC1/INA+: C310.1, R311.2, TP301.1, U701.1 (INA+)
/ADC1/INA-: C311.1, R312.2, TP302.1, U701.2 (INA-)
/ADC1/INB+: C411.1, R412.2, TP402.1, U701.8 (INB+)
/ADC1/INB-: C410.1, R411.2, TP401.1, U701.7 (INB-)
/ADC2/ADC.DA: U201.21 (IOL_14A_GBIN6), U801.14 (SDATAA)
/ADC2/ADC.DB: U201.22 (IOL_14B), U801.13 (SDATAB)
/ADC2/ADC.SCK: U201.15 (IOL_10A), U201.20 (IOL_13B_GBIN7), U701.15 (SCLK), U801.15 (SCLK)
/ADC2/ADC.~CS: U201.23 (IOL_17A), U801.10 (~CS)
/ADC2/INA+: C510.1, R511.2, TP501.1, U801.1 (INA+)
/ADC2/INA-: C511.1, R512.2, TP502.1, U801.2 (INA-)
/ADC2/INB+: C611.1, R612.2, TP602.1, U801.8 (INB+)
/ADC2/INB-: C610.1, R611.2, TP601.1, U801.7 (INB-)
/Clock Output/CLK0: R907.2, U1001.3 (A)
/Clock Output/CLK1: R201.1, U1001.1 (B)
/Clock Output/CLK_SEL: U201.60 (IOB_95), U1001.6 (~A/B)
/Clock Output/OUT: C1004.2, D1003.1 (K), J106.1 (In), JP1001.2 (B), R1002.2
/Clock Output/VDD_3V3: C1002.2, C1003.2, FB1001.2, U1001.5, U1002.5
/Extension Connector/5VEXT: F1201.1, J1401.2
/Extension Connector/DIR12: R1401.1, R1402.2, U1401.2 (1DIR)
/Extension Connector/DIR34: R1403.1, R1404.2, U1401.3 (2DIR)
/Extension Connector/DIR56: R1405.1, R1406.2, U1402.2 (1DIR)
/Extension Connector/DIR78: R1407.1, R1408.2, U1402.3 (2DIR)
/Extension Connector/EXT_IO1: J1401.5, RN1403.8 (R1.2)
/Extension Connector/EXT_IO2: J1401.7, RN1403.7 (R2.2)
/Extension Connector/EXT_IO3: J1401.9, RN1403.6 (R3.2)
/Extension Connector/EXT_IO4: J1401.11, RN1403.5 (R4.2)
/Extension Connector/EXT_IO5: J1401.13, RN1404.8 (R1.2)
/Extension Connector/EXT_IO6: J1401.15, RN1404.7 (R2.2)
/Extension Connector/EXT_IO7: J1401.17, RN1404.6 (R3.2)
/Extension Connector/EXT_IO8: J1401.19, RN1404.5 (R4.2)
/Extension Connector/EXT_VDD3V3: C1404.1, D1402.1 (K), J1401.1
/Extension Connector/EXT_VDDIO: C1403.1, D1401.1 (K), FB1401.1, J1401.3
/Extension Connector/IO1: RN1401.1 (R1.1), U201.44 (IOB_72)
/Extension Connector/IO2: RN1401.2 (R2.1), U201.43 (IOB_71)
/Extension Connector/IO3: RN1401.3 (R3.1), U201.42 (IOB_64)
/Extension Connector/IO4: RN1401.4 (R4.1), U201.41 (IOB_63)
/Extension Connector/IO5: RN1402.1 (R1.1), U201.39 (IOB_61)
/Extension Connector/IO6: RN1402.2 (R2.1), U201.38 (IOB_57)
/Extension Connector/IO7: RN1402.3 (R3.1), U201.37 (IOB_56)
/Extension Connector/IO8: RN1402.4 (R4.1), U201.34 (IOL_25B)
/Extension Connector/VDDIO: C1405.1, C1406.1, FB1401.2, U1401.16 (VCCB), U1402.16 (VCCB)
/FPGA/CLK_20MHZ: R906.2, U201.49 (IOB_81_GBIN5), U201.52 (IOB_82_GBIN4)
/FPGA/FIFO.CLKOUT: U201.74 (IOR_110), U1302.32 (ACBUS5)
/FPGA/FIFO.D0: U201.90 (IOR_138), U1302.16 (ADBUS0)
/FPGA/FIFO.D1: U201.88 (IOR_137), U1302.17 (ADBUS1)
/FPGA/FIFO.D2: U201.87 (IOR_136), U1302.18 (ADBUS2)
/FPGA/FIFO.D3: U201.85 (IOR_128), U1302.19 (ADBUS3)
/FPGA/FIFO.D4: U201.84 (IOR_120), U1302.21 (ADBUS4)
/FPGA/FIFO.D5: U201.83 (IOR_119), U1302.22 (ADBUS5)
/FPGA/FIFO.D6: U201.82 (IOR_118), U1302.23 (ADBUS6)
/FPGA/FIFO.D7: U201.81 (IOR_117), U1302.24 (ADBUS7)
/FPGA/FIFO.SIWU: U201.75 (IOR_111), U1302.30 (ACBUS4)
/FPGA/FIFO.~OE: U201.73 (IOR_109), U1302.33 (ACBUS6)
/FPGA/FIFO.~RD: U201.78 (IOR_114), U1302.28 (ACBUS2)
/FPGA/FIFO.~RXF: U201.80 (IOR_116), U1302.26 (ACBUS0)
/FPGA/FIFO.~TXE: U201.79 (IOR_115), U1302.27 (ACBUS1)
/FPGA/FIFO.~WR: U201.76 (IOR_112), U1302.29 (ACBUS3)
/FPGA/FT_IO.CDONE: R206.2, TP201.1, U201.65 (CDONE), U1302.44 (BDBUS5)
/FPGA/FT_IO.IO1: U201.64 (IOB_104_CBSEL1), U1302.45 (BDBUS6)
/FPGA/FT_IO.IO2: U201.63 (IOB_103_CBSEL0), U1302.46 (BDBUS7)
/FPGA/FT_IO.~CRESET: R205.2, TP202.1, U201.66 (~CRESET), U1302.43 (BDBUS4)
/FPGA/FT_SPI.MISO: U201.68 (IOB_106_SDI), U202.2 (DO/IO1), U1302.40 (BDBUS2)
/FPGA/FT_SPI.MOSI: U201.67 (IOB_105_SDO), U202.5 (DI/IO0), U1302.39 (BDBUS1)
/FPGA/FT_SPI.SCK: U201.70 (IOB_107_SCK), U202.6 (CLK), U1302.38 (BDBUS0)
/FPGA/FT_SPI.~CS: R202.2, U201.71 (IOB_108_SS), U202.1 (~CS), U1302.41 (BDBUS3)
/FPGA/LED.IN_G1: R107.1, U201.28 (IOL_23A)
/FPGA/LED.IN_G2: R109.1, U201.26 (IOL_18B)
/FPGA/LED.IN_G3: R111.1, U201.33 (IOL_25A)
/FPGA/LED.IN_G4: R113.1, U201.32 (IOL_24B)
/FPGA/LED.IN_R1: R106.1, U201.24 (IOL_17B)
/FPGA/LED.IN_R2: R108.1, U201.25 (IOL_18A)
/FPGA/LED.IN_R3: R110.1, U201.29 (IOL_23B)
/FPGA/LED.IN_R4: R112.1, U201.31 (IOL_24A)
/FPGA/LED.STS_G: R104.1, U201.94 (IOR_141_GBIN2)
/FPGA/LED.STS_R: R103.1, U201.93 (IOR_140_GBIN3)
/FPGA/QSPI_IO2: R203.2, U201.62 (IOB_102), U202.3 (~WP/IO2)
/FPGA/QSPI_IO3: R204.2, U201.61 (IOB_96), U202.7 (~HOLD/IO3)
/FPGA/REF_CLK_IN: R1105.2, U201.56 (IOB_94)
/FPGA/SRAM.A0: U201.144 (IOT_222), U203.1 (A0)
/FPGA/SRAM.A1: U201.143 (IOT_221), U203.2 (A1)
/FPGA/SRAM.A2: U201.142 (IOT_220), U203.3 (A2)
/FPGA/SRAM.A3: U201.141 (IOT_219), U203.4 (A3)
/FPGA/SRAM.A4: U201.139 (IOT_217), U203.5 (A4)
/FPGA/SRAM.A5: U201.116 (IOT_173), U203.18 (A5)
/FPGA/SRAM.A6: U201.115 (IOT_172), U203.19 (A6)
/FPGA/SRAM.A7: U201.114 (IOT_171), U203.20 (A7)
/FPGA/SRAM.A8: U201.113 (IOT_170), U203.21 (A8)
/FPGA/SRAM.A9: U201.112 (IOT_169), U203.22 (A9)
/FPGA/SRAM.A10: U201.97 (IOR_147), U203.23 (A10)
/FPGA/SRAM.A11: U201.98 (IOR_148), U203.24 (A11)
/FPGA/SRAM.A12: U201.99 (IOR_152), U203.25 (A12)
/FPGA/SRAM.A13: U201.101 (IOR_160), U203.26 (A13)
/FPGA/SRAM.A14: U201.102 (IOR_161), U203.27 (A14)
/FPGA/SRAM.A15: U201.10 (IOL_5B), U203.42 (A15)
/FPGA/SRAM.A16: U201.11 (IOL_8A), U203.43 (A16)
/FPGA/SRAM.A17: U201.12 (IOL_8B), U203.44 (A17)
/FPGA/SRAM.D0: U201.137 (IOT_215), U203.7 (I/O0)
/FPGA/SRAM.D1: U201.136 (IOT_214), U203.8 (I/O1)
/FPGA/SRAM.D2: U201.135 (IOT_213), U203.9 (I/O2)
/FPGA/SRAM.D3: U201.134 (IOT_212), U203.10 (I/O3)
/FPGA/SRAM.D4: U201.121 (IOT_181), U203.13 (I/O4)
/FPGA/SRAM.D5: U201.120 (IOT_179), U203.14 (I/O5)
/FPGA/SRAM.D6: U201.119 (IOT_178), U203.15 (I/O6)
/FPGA/SRAM.D7: U201.118 (IOT_177), U203.16 (I/O7)
/FPGA/SRAM.D8: U201.104 (IOR_164), U203.29 (I/O8)
/FPGA/SRAM.D9: U201.105 (IOR_165), U203.30 (I/O9)
/FPGA/SRAM.D10: U201.106 (IOR_166), U203.31 (I/O10)
/FPGA/SRAM.D11: U201.107 (IOR_167), U203.32 (I/O11)
/FPGA/SRAM.D12: U201.1 (IOL_2A), U203.35 (I/O12)
/FPGA/SRAM.D13: U201.2 (IOL_2B), U203.36 (I/O13)
/FPGA/SRAM.D14: U201.3 (IOL_3A), U203.37 (I/O14)
/FPGA/SRAM.D15: U201.4 (IOL_3B), U203.38 (I/O15)
/FPGA/SRAM.~CS: U201.138 (IOT_216), U203.6 (~CS)
/FPGA/SRAM.~LB: U201.7 (IOL_4A), U203.39 (~LB)
/FPGA/SRAM.~OE: U201.9 (IOL_5A), U203.41 (~OE)
/FPGA/SRAM.~UB: U201.8 (IOL_4B), U203.40 (~UB)
/FPGA/SRAM.~WE: U201.117 (IOT_174), U203.17 (~WE)
/FPGA/VCXO_DAC.DIN: U201.45 (IOB_73), U901.7 (DIN)
/FPGA/VCXO_DAC.SCK: U201.47 (IOB_79), U901.6 (SCLK)
/FPGA/VCXO_DAC.~SYNC: U201.48 (IOB_80), U901.5 (~SYNC)
/FTDI/FT_3V3: C1209.1, C1303.1, C1304.1, C1305.1, C1307.1, C1309.1, C1313.1, D1203.1 (K), FB1301.2, FB1302.2, Q1201.1 (G), R1303.2, R1305.2, R1307.2, R1308.2, TP1203.1, U1204.4 (Vout), U1301.6 (ORG), U1301.8 (VCC), U1302.14 (~RESET), U1302.20 (VCCIO), U1302.31 (VCCIO), U1302.42 (VCCIO), U1302.50 (VREGIN), U1302.56 (VCCIO)
/FTDI/FT_+1V8: C1306.1, C1308.1, C1312.1, C1316.1, U1302.12 (VCORE), U1302.37 (VCORE), U1302.49 (VREGOUT), U1302.64 (VCORE)
/FTDI/FT_VPHY: C1310.1, C1314.1, FB1301.1, U1302.4 (VPHY)
/FTDI/FT_VPLL: C1311.1, C1315.1, FB1302.1, U1302.9 (VPLL)
/FTDI/USB_D+: D1301.2 (K), J105.3 (D+), U1302.8 (DP)
/FTDI/USB_D-: D1301.1 (K), J105.2 (D-), U1302.7 (DM)
/FTDI/~PWREN: Q1201.2 (S), U1302.60 (~PWREN)
/FTDI/~PWRSAV: R1301.1, R1302.2, U1302.59 (BCBUS7)
/Input Amplifier 1/IN: C302.1, D301.2 (A2), J101.1 (In), L301.1
/Input Amplifier 1/VOCM: C101.2, C304.1, C404.1, C504.1, C604.1, R101.1, R102.2, U301.2 (VOCM), U401.2 (VOCM), U501.2 (VOCM), U601.2 (VOCM)
/Input Amplifier 2/IN: C402.1, D401.2 (A2), J102.1 (In), L401.1
/Input Amplifier 3/IN: C502.1, D501.2 (A2), J103.1 (In), L501.1
/Input Amplifier 4/IN: C602.1, D601.2 (A2), J104.1 (In), L601.1
/Power Supply/5VEXT_CLEAN: C1203.1, FB1201.1, R1208.1, R1212.2, TP1201.1
/Power Supply/+5VFTDI: C1206.1, R1208.2, R1209.1, R1211.1, U1204.1 (~SHDN), U1204.2 (Vin)
/Power Supply/VBUS: F1202.1, J105.1 (VBUS)
/Power Supply/VBUS_CLEAN: C1204.1, C1205.1, FB1202.1, Q1202.4 (S), R1207.1, R1209.2, R1301.2, TP1202.1
/Reference Clock Input/IN: C1102.1, D1101.2 (K), J107.1 (In), JP1101.1 (A), R1101.2
/VCXO/VCXO_VCC: C905.2, FB901.2, X901.6 (VCC)
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

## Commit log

2022-01-25 First commit: some sketches of analog frontend schematic
    [analog_frontend.kicad_sch, analog_input_amp.kicad_sch, lwdo-sdr.kicad_pcb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]
2022-02-03 Update: slowly drawing schematic
    [analog_frontend.kicad_sch, analog_input_amp.kicad_sch, lwdo-sdr.kicad_pcb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]
2022-02-06 Schematic: added VCTCXO, clk out, ref in, separated power supply into a new sheet
    [analog_input_amp.kicad_sch, clk_out.kicad_sch, lwdo-sdr.kicad_sch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]
2022-02-09 Schematic updated
    [analog_input_amp.kicad_sch, clk_out.kicad_sch, ftdi.kicad_sch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]
2022-02-14 Schematic sketching done
    [analog_input_amp.kicad_sch, clk_out.kicad_sch, extconn.kicad_sch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]
2022-02-15 Update schematic layout, separate into sheets
    [adc.kicad_sch, analog_input_amp.kicad_sch, clk_out.kicad_sch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]
2022-02-16 Schematic update
    [adc.kicad_sch, analog_input_amp.kicad_sch, clk_out.kicad_sch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]
2022-02-20 Schematic: better LDO output capacitor selection, clarified BOM
    [adc.kicad_sch, analog_input_amp.kicad_sch, clk_out.kicad_sch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]
2022-02-20 Schematic: yet another update -Improve way caps are specified once again -Update cap voltages based on ESD simulation -Make anti-aliasing LC filter more practical - with much less inductors -Specify 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
    [adc.kicad_sch, analog_input_amp.kicad_sch, clk_out.kicad_sch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]
2022-02-20 Schematic: change mosfets in VBUS switcher
    [lwdo-sdr.kicad_sch, power_supply.kicad_sch]
2022-02-20 Schematic: change order of level indicator LEDs from 1-3-2-4 to 1-2-3-4
    [lwdo-sdr.kicad_sch]
2022-02-20 Schematic: add PNs for resistors
    [analog_input_amp.kicad_sch, clk_out.kicad_sch, extconn.kicad_sch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]
2022-04-03 Combined update (kicad 6.0.4..) - Update schematic to kicad 6.0.4 - Assign footprints for SMA connectors - Replace MCP1825T with MCP1824T (chip shortages..)
    [adc.kicad_sch, analog_input_amp.kicad_sch, clk_out.kicad_sch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]
2022-04-06 Replace TL431PK (sot89) with TL431AFDT (sot23)
    - Fix tl431 value & footprint (kicad 6.0.4 bug)
    [lwdo-sdr.kicad_sch, power_supply.kicad_sch]
2022-04-06 Remove unused schematic file
    [analog_frontend.kicad_sch]
2022-04-06 Add DOT050 VCTCXO footprint
2022-04-06 Add Kingbright WP130WCP footprint
2022-04-06 Assign WP130WCP and DTO050 footprints in schematic
    [lwdo-sdr.kicad_sch, vcxo.kicad_sch]
2022-04-06 Add 3v3 TVS to extconn VDD supply rail
    [extconn.kicad_sch, lwdo-sdr.kicad_sch]
2022-04-06 PN list: replace PTVSxxS1UTR with PTVSxxS1UR
    [lwdo-sdr.kicad_sch, power_supply.kicad_sch]
2022-04-06 Schematic: add mounting holes
    [lwdo-sdr.kicad_sch]
2022-04-06 Add and use Superbat SMA connector footprint
    [lwdo-sdr.kicad_sch]
2022-04-07 Schematic: reconnect SRAM to ease PCB routing
    [fpga.kicad_sch]
2022-04-07 Update footprints: - SOD323F, SOD323, SOD123W... intead of generic handsolder version - 3225 xtal - use handsolder footprint - do not use handsolder version for ferrite beads - use SOT-23-6 instead o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
    [analog_input_amp.kicad_sch, clk_out.kicad_sch, extconn.kicad_sch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]
2022-04-08 Add two GND testpoints to the schematic
    [lwdo-sdr.kicad_sch]
2022-04-08 PCB: begin layout - Board edge - Al extrusion clearances - Mounting holes - Connectors - FPGA-SRAM A/D buses
    [lwdo-sdr.kicad_pcb]
2022-04-19 Redesign VOCM network, power FDA from 3v3 directly
    [analog_input_amp.kicad_sch, lwdo-sdr.kicad_sch]
2022-04-19 Rename USB dp,dm to d+,d- to make pcbnew happy
    [ftdi.kicad_sch, lwdo-sdr.kicad_sch]
2022-04-19 FPGA: connect LEDs differently
    [fpga.kicad_sch]
2022-04-19 FTDI: add extra decoupling
    [analog_input_amp.kicad_sch, ftdi.kicad_sch, lwdo-sdr.kicad_sch]
2022-04-19 Replace 10uf al-elco by tantalum -Space savings (0805 vs 4mm cylinder)
    [adc.kicad_sch, fpga.kicad_sch, lwdo-sdr.kicad_sch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]
2022-04-19 PCB: wip
    [lwdo-sdr.kicad_pcb]
2022-04-19 FPGA: swap QSPI pins
    [fpga.kicad_sch]
2022-04-19 74lvc2g04: swap units
    [lwdo-sdr.kicad_sch, ref_in.kicad_sch]
2022-04-19 ExtConn: fix bug in net naming
    [extconn.kicad_sch]
2022-04-19 Extconn: remove redundant 100n cap
    [extconn.kicad_sch, lwdo-sdr.kicad_sch]
2022-04-19 Reconnect some things to simplify PCB routing
    [clk_out.kicad_sch, fpga.kicad_sch, lwdo-sdr.kicad_pcb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]
2022-04-19 Power supply rework - Only fixed power source selection via 0ohm jumpers - Make it simpler
    [lwdo-sdr.kicad_sch, power_supply.kicad_sch]
2022-04-19 Fix footprints, values and PNs
    [lwdo-sdr.kicad_sch, power_supply.kicad_sch, ref_in.kicad_sch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]
2022-04-19 Power supply: add +5VFTDI net, prettify net names
    [lwdo-sdr.kicad_sch, power_supply.kicad_sch]
2022-04-19 FT2232H: pull BCBUS2&3 high
    [ftdi.kicad_sch]
2022-04-20 FPGA: remove support for SPI slave mode - Now FTDI can only talk to QSPI flash - FPGA boots exclusively from QSPI flash
    [fpga.kicad_sch, lwdo-sdr.kicad_sch]
2022-04-20 PCB: WIP - Power supply almost laid out
    [lwdo-sdr.kicad_pcb]
2022-04-21 FPGA: swap CLK_OUT and CLK_SEL
    [fpga.kicad_sch]
2022-04-22 VCXO: remove Taitien vctcxo, add extra decoupling
    [lwdo-sdr.kicad_sch, vcxo.kicad_sch]
2022-04-22 VCXO, REF_IN: add reflection damping resistors
    [lwdo-sdr.kicad_sch, ref_in.kicad_sch, vcxo.kicad_sch]
2022-04-23 extconn: add 3v3d output
    [extconn.kicad_sch, lwdo-sdr.kicad_sch]
2022-04-24 PCB: WIP Schematic: minor changes (decoupling, logic element ordering)
    [analog_input_amp.kicad_sch, clk_out.kicad_sch, lwdo-sdr.kicad_pcb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]
2022-04-25 Update schematic: - Redesign of decoupling based on swcad modelling (predominantly use 1uf, no paralleled caps) - Reroute REF_CLK_IN, CLK_SEL net to different FPGA pins - Some net renaming - Ext conn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
    [adc.kicad_sch, analog_input_amp.kicad_sch, clk_out.kicad_sch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]
2022-04-25 PCB: enable fillets for some zones, fix DRC errors
    [lwdo-sdr.kicad_pcb]
2022-04-25 PCB: top silkscreen done
    [lwdo-sdr.kicad_pcb]
2022-04-25 PCB: add silkscreen artwork + revision - Artwork by https://twitter.com/onisarashi/status/1423701946305847296
    [lwdo-sdr.kicad_pcb]
2022-04-25 PCB: place bottom silkscreen - DRC passing except for some known silkscreen overlaps
    [lwdo-sdr.kicad_pcb]
2022-04-26 Use standard Molex 73251-2201 footprint for SMA
    [lwdo-sdr.kicad_pcb, lwdo-sdr.kicad_sch]
2022-04-26 PCB: update attribution
    [lwdo-sdr.kicad_pcb]
2022-04-26 PCB: reroute CLK_20MHZ trace
    [lwdo-sdr.kicad_pcb]
2022-04-26 PCB: improve FPGA/SRAM power routing (use zones)
    [lwdo-sdr.kicad_pcb]
2022-04-26 PCB: silkscreen improvement
    [lwdo-sdr.kicad_pcb]
2022-04-27 - Add matching / anti-ring resistors to clock nets - Use 0603 resistors for anti-ring - Improve CLK_OUT routing
    [fpga.kicad_sch, lwdo-sdr.kicad_pcb, lwdo-sdr.kicad_sch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]
2022-04-27 PCB: minor fix for footprints - no more DRC warnings
    [lwdo-sdr.kicad_pcb]
2022-04-27 Redesign FDA input overload protection
    [analog_input_amp.kicad_sch, lwdo-sdr.kicad_pcb, lwdo-sdr.kicad_sch]
2022-04-28 Add testpoints for CDONE and CRESET
    [fpga.kicad_sch, lwdo-sdr.kicad_pcb, lwdo-sdr.kicad_sch]
2022-04-28 Fix: correct BAT54 PN and package - SOD323 not SOD323F
    [analog_input_amp.kicad_sch, clk_out.kicad_sch, extconn.kicad_sch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]
2022-04-28 - Replace 0.18 track by 0.2 (0.18 used by mistake) - Prepare fabrication outputs (don't know why does kicad change a lot of values in PCB file here?)
    [lwdo-sdr.kicad_pcb]
2022-05-13 Add schematic and pcb plots in PDF
